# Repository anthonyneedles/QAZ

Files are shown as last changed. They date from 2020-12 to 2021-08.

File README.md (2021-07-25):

# **QAZ**

QAZ 65% Side

## Table of Contents

1. [Boards](#boards)
1. [About This Project](#about-this-project)
    1. [File Structure](#file-structure)
    1. [Dependencies](#dependencies)
1. [Programming](#programming)
1. [Software](#software)
1. [Building](#building)

## **Boards**

### [**QAZ 65%**](docs/guides/QAZ_65.md)

### [**QAZ Media**](docs/guides/QAZ_Media.md)

## **About This Project**

The QAZ project was created as a way for me to learn the USB protocol by writing a bare-metal USB
driver. Since a keyboard is a relatively simple USB device, and I like mechanical keyboards, I
decided that it would be a perfect project. The QAZ project is planned to support various different
keyboard layouts (only 65% and a Media board for now).

This repository holds files for both the software and hardware portions of this project. The
software consists of C++ source and header files, built using Make. Building is only supported
in Debian-based systems. CMSIS is used for some MCU hardware abstraction.

The PCB(s) for the different board versions have their schematic and layouts designed in KiCad,
which are contained in this library and can be manufactured in any generic fabrication house.

There is a maker space at my work that has a laser cutter that can cut acrylic, so decided to try
to keep costs down and make a "sandwich" case, which consists of several stacked layers of acrylic.

### **File Structure**

```
└── QAZ/
    ├── build/
    │   └── CMake build directory
    │
    ├── docs/
    │   │── guides/
    │   │   └── board-specific info, software info, etc.
    │   │
    │   ├── doxygen/
    │   │   └── Doxygen html output
    │   │
    │   └── media/
    │       └── diagrams, pictures, etc.
    │
    ├── hardware/
    │   ├── common/
    │   │   └── hardware utility used by both (e.g. KiCad libraries)
    │   │
    │   └── QAZ_*/
    │       └── PCB/case layer subdirectories for each QAZ configuration
    │
    ├── scripts/
    │   └── useful project scripts (cpplint.py, Doxyfile, etc.)
    │
    ├── src/
    │   └── all source files/module subdirectories, source-level CMakeLists.txt
    │
    └── LICENSE, README, top-level Makefile/CMakeLists.txt
```

The `docs\doxygen` and `build` directories are not tracked, and get made when the project is built.
The files in these directories are removed when the project is cleaned with `make clean`.

## **Programming**

The board programming guide can be found at [`docs/guides/Programming.md`](docs/guides/Programming.md).

## **Software**

The software guide can be found at [`docs/guides/Software.md`](docs/guides/Software.md).

## **Building**

The software building guide can be found at [`docs/guides/Building.md`](docs/guides/Building.md).

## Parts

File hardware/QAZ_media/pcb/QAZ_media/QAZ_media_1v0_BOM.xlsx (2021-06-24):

BOM Index | Part Number | Part Description | QTY | Unit Cost | Extended Cost | Schematic Reference(s) | Product Link
1 | CC0603KRX7R8BB104 | CAP CER 0.1UF 25V X7R 0603 | 4 | $0.10 | $0.40 | C1, C5, C7, C8 | https://www.digikey.com/product-detail/en/yageo/CC0603KRX7R8BB104/311-1341-1-ND/2103125
2 | CC0805KRX5R5BB475 | CAP CER 4.7UF 6.3V X5R 0805 | 1 | $0.17 | $0.17 | C2 | https://www.digikey.com/product-detail/en/yageo/CC0805KRX5R5BB475/311-3422-1-ND/7164443
3 | CL10C160JB8NNNC | CAP CER 16PF 50V C0G/NP0 0603 | 2 | $0.10 | $0.20 | C3, C4 | https://www.digikey.com/product-detail/en/samsung-electro-mechanics/CL10C160JB8NNNC/1276-2204-1-ND/3890290
4 | CL10B105MO8NNWC | CAP CER 1UF 16V X7R 0603 | 2 | $0.10 | $0.20 | C6, C9 | https://www.digikey.com/product-detail/en/samsung-electro-mechanics/CL10B105MO8NNWC/1276-6524-1-ND/5961383
5 | GCM188R72A103KA37D | CAP CER 10000PF 100V X7R 0603 | 2 | $0.10 | $0.20 | C10, C11 | https://www.digikey.com/en/products/detail/murata-electronics/GCM188R72A103KA37D/1641655
6 | USB4085-GF-A | CONN RCPT USB2.0 TYPEC 16POS | 1 | $1.37 | $1.37 | CN1 | https://www.digikey.com/product-detail/en/gct/USB4085-GF-A/2073-USB4085-GF-ACT-ND/9859733
7 | 150060BS75000 | LED BLUE CLEAR 0603 SMD | 1 | $0.16 | $0.16 | D1 | https://www.digikey.com/product-detail/en/w%C3%BCrth-elektronik/150060BS75000/732-4966-1-ND/4489893
8 | 150060VS75000 | LED GREEN CLEAR 0603 SMD | 1 | $0.14 | $0.14 | D2 | https://www.digikey.com/en/products/detail/w%C3%BCrth-elektronik/150060VS75000/4489906
9 | LTST-C190KRKT | LED RED CLEAR CHIP SMD | 1 | $0.24 | $0.24 | D3 | https://www.digikey.com/product-detail/en/lite-on-inc/LTST-C190KRKT/160-1436-1-ND/386816
10 | HLMT-PL00 | LED AMBER CLEAR FLAT T/H AXIAL | 1 | $1.15 | $1.15 | D4 | https://www.digikey.com/en/products/detail/broadcom-limited/HLMT-PL00/637671
11 | S9345-ND | CONN JUMPER SHORTING 1.27MM GOLD | 3 | $0.27 | $0.81 | JP1, JP2, JP3 | https://www.digikey.com/en/products/detail/NPB02SVAN-RC/S9345-ND/2618270
12 | GRPB021VWVN-RC | CONN HEADER VERT 2POS 1.27MM | 3 | $0.25 | $0.75 | JP1, JP2, JP3 | https://www.digikey.com/en/products/detail/GRPB021VWVN-RC/S9014E-02-ND/1786438
13 | ERJ-3EKF2491V | RES SMD 2.49K OHM 1% 1/10W 0603 | 1 | $0.10 | $0.10 | R1 | https://www.digikey.com/en/products/detail/panasonic-electronic-components/ERJ-3EKF2491V/196192
14 | RMCF0603FT10K0 | RES 10K OHM 1% 1/10W 0603 | 12 | $0.10 | $1.20 | R2, R6, R7, R8, R10, R11, R12, R13, R14, R15, R17, R18 | https://www.digikey.com/en/products/detail/yageo/RC0603FR-0710KL/726880
15 | ERJ-3EKF1301V | RES SMD 1.3K OHM 1% 1/10W 0603 | 2 | $0.10 | $0.20 | R3, R4 | https://www.digikey.com/product-detail/en/panasonic-electronic-components/ERJ-3EKF1301V/P1-30KHCT-ND/198082
16 | RC0603FR-071K4L | RES SMD 1.4K OHM 1% 1/10W 0603 | 1 | $0.10 | $0.10 | R5 | https://www.digikey.com/en/products/detail/yageo/RC0603FR-071K4L/726861
17 | RC0603FR-075K1L | RES SMD 5.1K OHM 1% 1/10W 0603 | 2 | $0.10 | $0.20 | R9, R16 | https://www.digikey.com/product-detail/en/yageo/RC0603FR-075K1L/311-5-10KHRCT-ND/730215
18 | RC0603JR-070RL | RES SMD 0 OHM JUMPER 1/10W 0603 | 4 | $0.10 | $0.40 | SB1, SB2, SB3, SB4 | https://www.digikey.com/product-detail/en/yageo/RC0603JR-070RL/311-0.0GRCT-ND/729622
19 | JS102011SCQN | SWITCH SLIDE SPDT 300MA 6V | 1 | $0.73 | $0.73 | SW1 | https://www.digikey.com/en/products/detail/c-k/JS102011SCQN/3753547
20 | NCA2 | KEY STYLE PB, SPST, MOM, BLACK A | 4 | $0.94 | $3.76 | SW2, SW3, SW5, SW6 | https://www.digikey.com/en/products/detail/cit-relay-and-switch/NCA2/12502939
21 | PEC11L-4220F-S0015 | ROTARY ENCODER MECHANICAL 15PPR | 1 | $1.94 | $1.94 | SW4 | https://www.digikey.com/en/products/detail/bourns-inc/PEC11L-4220F-S0015/2440942
22 | OEDNI-75-4-7 | KNOB KNURLED 0.236" METAL | 1 | $7.95 | $7.95 | SW4 | https://www.digikey.com/en/products/detail/kilo-international/OEDNI-75-4-7/5970347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
23 | AP2112K-3.3TRG1 | IC REG LINEAR 3.3V 600MA SOT25 | 1 | $0.49 | $0.49 | U1 | https://www.digikey.com/product-detail/en/diodes-incorporated/AP2112K-3.3TRG1/AP2112K-3.3TRG1DICT-ND/4505257
24 | STM32F042C6T6 | IC MCU 32BIT 32KB FLASH 48LQFP | 1 | $2.94 | $2.94 | U2 | https://www.digikey.com/product-detail/en/stmicroelectronics/STM32F042C6T6/497-14648-ND/4815295
25 | ABM7-8.000MHZ-D2Y-T | CRYSTAL 8.0000MHZ 18PF SMD | 1 | $0.87 | $0.87 | Y1 | https://www.digikey.com/product-detail/en/abracon-llc/ABM7-8.000MHZ-D2Y-T/535-9831-1-ND/2001454
Total |  |  |  |  | $26.67

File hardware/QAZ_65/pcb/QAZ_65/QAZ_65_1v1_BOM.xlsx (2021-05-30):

BOM Index | Part Number | Part Description | QTY | Unit Cost | Extended Cost | Schematic Reference(s) | Product Link
1 | CC0805KRX5R5BB475 | CAP CER 4.7UF 6.3V X5R 0805 | 1 | $0.17 | $0.17 | C1 | https://www.digikey.com/product-detail/en/yageo/CC0805KRX5R5BB475/311-3422-1-ND/7164443
2 | CC0603KRX7R8BB104 | CAP CER 0.1UF 25V X7R 0603 | 7 | $0.10 | $0.70 | C2, C4, C5, C8, C10, C11, C13 | https://www.digikey.com/product-detail/en/yageo/CC0603KRX7R8BB104/311-1341-1-ND/2103125
3 | CL10B105MO8NNWC | CAP CER 1UF 16V X7R 0603 | 4 | $0.10 | $0.40 | C3, C9, C12, C14 | https://www.digikey.com/product-detail/en/samsung-electro-mechanics/CL10B105MO8NNWC/1276-6524-1-ND/5961383
4 | CL10C160JB8NNNC | CAP CER 16PF 50V C0G/NP0 0603 | 2 | $0.10 | $0.20 | C6, C7 | https://www.digikey.com/product-detail/en/samsung-electro-mechanics/CL10C160JB8NNNC/1276-2204-1-ND/3890290
5 | USB4085-GF-A | CONN RCPT USB2.0 TYPEC 16POS | 1 | $1.37 | $1.37 | CN1 | https://www.digikey.com/product-detail/en/gct/USB4085-GF-A/2073-USB4085-GF-ACT-ND/9859733
6 | 150060BS75000 | LED BLUE CLEAR 0603 SMD | 1 | $0.50 | $0.50 | D1 | https://www.digikey.com/product-detail/en/w%C3%BCrth-elektronik/150060BS75000/732-4966-1-ND/4489893
7 | LTST-C191KGKT | LED GREEN CLEAR SMD | 1 | $0.28 | $0.28 | D2 | https://www.digikey.com/product-detail/en/lite-on-inc/LTST-C191KGKT/160-1446-1-ND/386834
8 | LTST-C190KRKT | LED RED CLEAR CHIP SMD | 1 | $0.26 | $0.26 | D3 | https://www.digikey.com/product-detail/en/lite-on-inc/LTST-C190KRKT/160-1436-1-ND/386816
9 | 1N4148FSCT-ND | DIODE SMALL SIGNAL SWITCHING 100V 0.15A 2-PIN DO-35 | 68 | $0.06 | $3.94 | D4, D5, D6, D7, D8, D9, D10, D11, D12, D13, D14, D15, D16, D17, D18, D19, D20, D21, D22, D23, D24, D25, D26, D27, D28, D29, D30, D31, D32, D33, D34, D35, D36, D37, D38, D39, D40, D41, D42, D43, D44, D45, D46, D47, D48, D49, D50, D51, D52, D53, D54, D55, D56, D57, D58, D59, D60, D61, D62, D63, D64, D65, D66, D67, D68, D69, D70, D71 | https://www.digikey.com/products/en?keywords=1N4148FSCT-ND
10 | 19-337C/RSBHGHC-A88/4T | TRI COLOR PCB TOP VIEW SMD LED R | 18 | $0.42 | $7.56 | D72, D73, D74, D75, D76, D77, D78, D79, D80, D81, D82, D83, D84, D85, D86, D87, D88, D89 | https://www.digikey.com/en/products/detail/everlight-electronics-co-ltd/19-337C-RSBHGHC-A88-4T/10059591
11 | S9345-ND | CONN JUMPER SHORTING 1.27MM GOLD | 3 | $0.27 | $0.81 | JP1, JP2, JP3 | https://www.digikey.com/en/products/detail/NPB02SVAN-RC/S9345-ND/2618270
12 | GRPB021VWVN-RC | CONN HEADER VERT 2POS 1.27MM | 3 | $0.25 | $0.75 | JP1, JP2, JP3 | https://www.digikey.com/en/products/detail/GRPB021VWVN-RC/S9014E-02-ND/1786438
13 | RC0603FR-071K69L | RES SMD 1.69K OHM 1% 1/10W 0603 | 1 | $0.10 | $0.10 | R1 | https://www.digikey.com/product-detail/en/yageo/RC0603FR-071K69L/311-1.69KHRCT-ND/729818
14 | RC0603FR-071KL | RES SMD 1K OHM 1% 1/10W 0603 | 5 | $0.10 | $0.50 | R10, R11, R12, R13, R14 | https://www.digikey.com/product-detail/en/yageo/RC0603FR-071KL/311-1.00KHRCT-ND/729790
15 | RC0603FR-0751RL | RES SMD 51 OHM 1% 1/10W 0603 | 6 | $0.10 | $0.60 | R16, R19, R22, R25, R28, R31 | https://www.digikey.com/en/products/detail/yageo/RC0603FR-0751RL/730228
16 | RMCF0603FT20R0 | RES 20 OHM 1% 1/10W 0603 | 12 | $0.10 | $1.20 | R17, R18, R20, R21, R23, R24, R26, R27, R29, R30, R32, R33 | https://www.digikey.com/en/products/detail/stackpole-electronics-inc/RMCF0603FT20R0/1942945
17 | RMCF0603FT10K0 | RES 10K OHM 1% 1/10W 0603 | 4 | $0.10 | $0.40 | R2, R3, R6, R35 | https://www.digikey.com/product-detail/en/stackpole-electronics-inc/RMCF0603FT10K0/RMCF0603FT10K0CT-ND/1943057
18 | RC0603FR-07100KL | RES SMD 100K OHM 1% 1/10W 0603 | 1 | $0.10 | $0.10 | R34 | https://www.digikey.com/en/products/detail/yageo/RC0603FR-07100KL/729836
19 | ERJ-3EKF1301V | RES SMD 1.3K OHM 1% 1/10W 0603 | 2 | $0.10 | $0.20 | R4, R5 | https://www.digikey.com/product-detail/en/panasonic-electronic-components/ERJ-3EKF1301V/P1-30KHCT-ND/198082
20 | RC0603FR-072KL | RES SMD 2K OHM 1% 1/10W 0603 | 2 | $0.10 | $0.20 | R7, R8 | https://www.digikey.com/en/products/detail/yageo/RC0603FR-072KL/727009
21 | RC0603FR-075K1L | RES SMD 5.1K OHM 1% 1/10W 0603 | 2 | $0.10 | $0.20 | R9, R15 | https://www.digikey.com/product-detail/en/yageo/RC0603FR-075K1L/311-5-10KHRCT-ND/730215
22 | RC0603JR-070RL | RES SMD 0 OHM JUMPER 1/10W 0603 | 21 | $0.10 | $2.10 | SB1, SB2, SB3, SB4, SB5, SB6, SB7, SB8, SB9, SB10, SB11, SB12, SB13, SB14, SB15, SB16, SB17, SB18, SB19, SB20, SB21 | https://www.digikey.com/product-detail/en/yageo/RC0603JR-070RL/311-0.0GRCT-ND/729622
23 | JS102011SCQN | SWITCH SLIDE SPDT 300MA 6V | 1 | $0.73 | $0.73 | SW1 | https://www.digikey.com/en/products/detail/c-k/JS102011SCQN/3753547
24 | - | CHERRY MX SWITCH, CLEAR, PCB MOUNT | 68 |  |  | SW2, SW3, SW4, SW5, SW6, SW7, SW8, SW9, SW10, SW11, SW12, SW13, SW14, SW15, SW16, SW17, SW18, SW19, SW20, SW21, SW22, SW23, SW24, SW25, SW26, SW27, SW28, SW29, SW30, SW31, SW32, SW33, SW34, SW35, SW36, SW37, SW38, SW39, SW40, SW41, SW42, SW43, SW44, SW45, SW46, SW47, SW48, SW49, SW50, SW51, SW52, SW53, SW54, SW55, SW56, SW57, SW58, SW59, SW60, SW61, SW62, SW63, SW64, SW65, SW66, SW67, SW68, SW69
25 | AP2112K-3.3TRG1 | IC REG LINEAR 3.3V 600MA SOT25 | 1 | $0.49 | $0.49 | U1 | https://www.digikey.com/product-detail/en/diodes-incorporated/AP2112K-3.3TRG1/AP2112K-3.3TRG1DICT-ND/4505257
26 | STM32F042C6T6 | IC MCU 32BIT 32KB FLASH 48LQFP | 1 | $2.94 | $2.94 | U2 | https://www.digikey.com/product-detail/en/stmicroelectronics/STM32F042C6T6/497-14648-ND/4815295
27 | IS31FL3746A-QFLS4-TR | IC LED DRIVER LIN DIM | 1 | $2.11 | $2.11 | U3 | https://www.digikey.com/en/products/detail/lumissil-microsystems/IS31FL3746A-QFLS4-TR/9759708
28 | ABM7-8.000MHZ-D2Y-T | CRYSTAL 8.0000MHZ 18PF SMD | 1 | $1.00 | $1.00 | Y1 | https://www.digikey.com/product-detail/en/abracon-llc/ABM7-8.000MHZ-D2Y-T/535-9831-1-ND/2001454
Total |  |  |  |  | $29.81

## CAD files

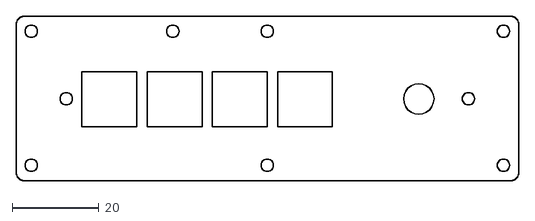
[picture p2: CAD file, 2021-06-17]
hardware/QAZ_media/layers/plate_layer_v1.dxf
115.7 x 37.9

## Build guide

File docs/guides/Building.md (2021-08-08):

# **QAZ Building**

## **Table of Contents**

1. [Dependencies](#dependencies)
1. [Make](#make)
1. [CMake](#cmake)
1. [Output](#output)

## **Dependencies**

Required APT packages for building:
- gcc-arm-none-eabi
- build-essential
- cmake (>= 3.16.3)

Required APT packages for utility targets and debugging:
- gdb-multiarch
- openocd
- stlink-tools
- doxygen
- graphviz
- python

Additionally, KiCad is used for PCB design.

## **Make**

QAZ uses `make` for top-level project building. This [Makefile](../../Makefile) handles all
building commands. These are the available commands:

- `QAZ` - Build complete software target

- `all` - Build software target, doxygen, and lint

- `docs` - Use Doxygen to create project documentation (with Graphviz graphs)

- `clean` - Removes all built files

- `lint` - Run cpplint.py on `src/`

- `flash` - Flash binary at 0x08000000, `make QAZ` if no binary

- `help` - Display the above

There are several variables that the user can set in a "user config"
Makefile. This file is *not* tracked by Git, so that local changes to it don't
need to be stashed/removed when committing. There exists a template of this
file [UserConfig.mk.template](../../UserConfig.mk.template) that the user
would ideally copy to `UserConfig.mk`, and make any desired changes.

These are the variables set in the user config:

- `BUILD_TYPE` - Debug or Release (i.e. debug print statements/asserts or not)

- `BOARD` - Which board to build for (dictates BSP)

A dummy marker file `.rebuild-marker` is used to ensure that whenever the top level
[Makefile](../../Makefile) is changed the system ALWAYS rebuilds. This ensures that partial
builds don't occur when changing the above variables.

## **CMake**

When building the output project, `cmake` will be invoked to generate the source-level
[Makefile](../../Makefile) in the `build/` directory, which will then be used to compile and
link the output executable.

The top-level [CMakeLists.txt](../../CMakeLists.txt) expects three variables: `TARGET`,
`CMAKE_BUILD_TYPE`, and `BSP`, which is nominally passed in by the top-level
[Makefile](../../Makefile) from the `TARGET`, `BUILD_TYPE`, and `BOARD` variables (respectively).
This file also defines our compilers/linkers, as well as all of the flags we pass to them. `src/`
is added as a subdirectory.

The source-level [CMakeLists](../../src/CMakeLists.txt) expects the same variables as above. This
file defines all C++, C, and Assembly files (paths relative to `src/`), as well as include
directories.

## **Output**

After building, output targets can be found in `build/src`. The default output target is `QAZ.elf`.
This is copied and converted to `QAZ.bin`. To help tracking .elf/.bin files, both are then copied
and renamed to: `${BOARD}_${BUILD_TYPE}_${GIT_STATE}_${GIT_HASH}.*` (`GIT_STATE` is either
`CLEAN` or `DIRTY`).

The .elf output can be used to program the given board by following the
[QAZ Programming guide](Programming.md).

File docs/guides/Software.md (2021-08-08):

# **QAZ Software**

## **Table of Contents**

1. [Clocks](#clocks)
1. [Time Slice Loop](#time-slice-loop)
1. [USB](#usb)
1. [Keyboard](#keyboard)
1. [Persistent Data](#persistent-data)

## **Clocks**

The STM32F042C6 has a default HS clock of 8MHz, and a HSI48 48MHz clock, which is specifically for
the USB peripheral. This clock has a terrible accuracy of +/-3% at room temperature, which is out
of spec of USB 2.0 tolerance. However, the USB peripheral has a special Clock Recovery System (CRS)
which dynamically adjusts the oscillator an adequate amount.

In the initial steps of this design, this HSI48 was used, but as of QAZ board v0.1 an external 8MHz
crystal supplies the HSE oscillator, which gets multiplied to 48MHz from the PLL, then finally
feeds the system core and USB peripheral.

## **Time Slice Loop**

The QAZ firmware does not operate on an RTOS, because it doesn't require stringent timing, but
rather a time slice superloop. The configuration of this is defined in
[core/time_slice.hpp](../../src/core/time_slice.hpp).

Tasks must be registered to the timeslice scheduler by calling `timeslice::register_task()`, with
the task period and function as parameters. Registered tasks are entered in a statically defined
task registry, so the maximum number of tasks is defined by `MAX_NUM_TASKS`.

While the timeslice loop is running, the internal 'time slice manager task' will make sure that
each task gets a chance to run every loop period. Specific task periods are created by only
calling the task function every N time slices (where N = Task Period / Loop Period).

**Task periods must be multiples of of the timeslice period. For a given set of task periods,
the timeslice period should be as large as possible.**

Currently, the time slice loop (`LOOP_PERIOD_MS`) is 5ms.

Task periods:
- **LED Heartbeat Task** - 500ms
- **Key Matrix Scan Task** - 20ms
- **Lighting Task** - 5ms
- **USB HID KB Task** - 20ms
- **USB HID Consumer Task** - 10ms

## **USB**

The QAZ project uses an entirely self-written USB low-level driver, which interacts directly with
the STM32 USB hardware peripheral. Additionally, there are Keyboard device and Consumer device USB
HID drivers, which utilizes the low-level driver to perform the required HID initialization and
reporting.

In the device descriptor the following fields are set for each board:
- idVendor = `0xC01D`
- idProduct = `0xAA22`
- bcdDevice = Version of board (e.g. `1.10`)
- iManufacturer = String descriptor 1 ("`anthonyneedles`")
- iProduct =  String descriptor 2 (e.g. "`qaz media`")

## **Keyboard**

The keyboard layout for a QAZ configuration is defined in the BSP file for the board. `COLS` and
`ROWS` define the physical pins of the key matrix. The `BASE_TABLE` and `FN_TABLE` defines the
keyboard layout for a given row and column pin, with column0/row0 being the "top left" of the
keyboard.

The entries in the key layout table correspond to a given entry in the USB HID usages table, as
well as "extra" codes added that correspond not to actual codes, but actions to perform. For
instance, changing the keyboard RGB LED brightness and color. `NONE` is used when no keycode or
action corresponds to with the key on the layer.

There is a special key called `FN`, which when pressed switches the key layout layer from Base to
Fn. This means the any other key also pressed with the `FN` key will result in the `FN_TABLE`
being used to translate key presses into key codes/actions rather than `BASE_TABLE`. This allows
almost double the amount of "keys" on the keyboard.

For example, in the QAZ 65%, pressing just the "1/!" physical key results in the Base keycode
(0x1E) for that key being sent to the host. If instead the "1/!" physical key AND the "FN"
physical key were pressed, then the Fn keycode (0x3A, the F1 keycode) for that given key is
sent instead.

It important to keep in mind, that since keyboard layouts are not exact grids, not every column/row
pin corresponds to a physical pin, but must be defined in each table grid (and given a `NONE` value).

Additionally, any of the keys can also be defined in `CALLBACK_KEY_TABLE`, which (when a key with
that code is pressed) results in the key NOT being placed in the output key buffer (used by the USB
KB HID task to send keycodes to the host), but having a callback (initially defined as `weak`)
called. This allows other modules defining the callback and implementing a hook to execute when the
given key is pressed (seen in RGB LED module).

## **Persistent Data**

There are several data words that are saved in the internal flash, as it is desired that they
persist between PORs (for instance, the lighting settings). This is achieved by emulating the
flash as EEPROM.

This emulation requires two full flash pages be used. In order to maximize the available flash for
the program, the last two pages are used. Since each page is 1kB, this means that the available
flash in the STM32F042C6 for the program is 30kB, with the last 2kB being reserved.

New data words can be added by adding entries to the `PERSIST_DATA_TABLE` in
[src/qaz/persist.hpp](../../src/flash/persist.hpp), and increasing `NB_OF_VAR` in
[src/flash/eeprom.h](../../src/flash/eeprom.h).

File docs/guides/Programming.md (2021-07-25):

# **QAZ Programming**

## **Table of Contents**

1. [Required Software](#required-software)
1. [Programming](#programming)

## **Required Software**

[STM32CubeProgrammer](https://www.st.com/en/development-tools/stm32cubeprog.html) is used to
connect to the STM32 bootloader, to program a board via USB DFU (nominally) or SWD (JTAG).

## **Programming**

The following steps should be followed to program a given QAZ board.

1. Unplug the board and flip the boot switch, accessible on the back of the board, to the "PG" 
side.
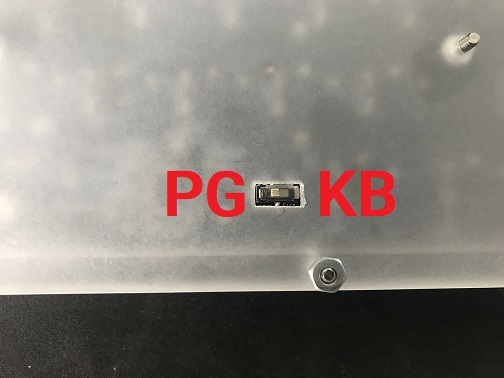
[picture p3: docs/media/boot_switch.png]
QAZ Boot Switch

1. Plug the board back in, and open STM32CubeProgrammer.
1. Select "USB" as method of programming. "Port" should be "USB1", as the bootloader device should
be automatically detected. If not, hit the refresh button to the right. When the PID/VID are
filled, hit the "Connect" button, which should result in "Data read successfully" in the log. Open
the "Erasing & Programming" window by clicking on the second icon on the left. Open "Browse", and
select the desired .elf program file. Finally, click "Start Programming". 
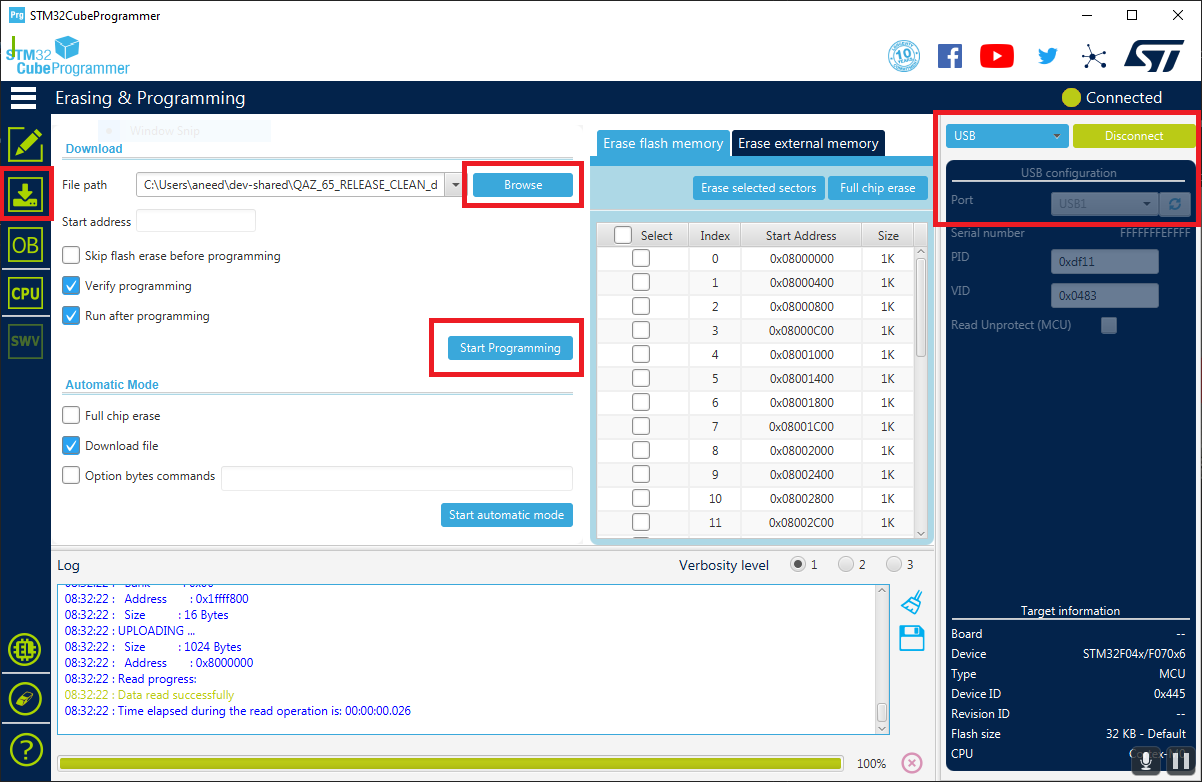
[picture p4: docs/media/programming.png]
STM32 Bootloader

1. Unplug the board, flip the boot switch to the "KB" side, and plug the board back in. The board
should now be programmed.

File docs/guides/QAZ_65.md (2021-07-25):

# **QAZ 65% Keyboard**

QAZ 65% Side

## **Table of Contents**

1. [About This Board](#about-this-board)
1. [Software](#software)
1. [Hardware](#hardware)
    1. [PCB](#pcb)
    1. [Case](#case)
1. [Previous Versions](#previous-versions)
    1. [v1.0](#v1.0)

## **About This Board**

The QAZ 65% is a 68-key keyboard in a non-standard configuration. It features RGB back lighting,
with configurable lighting.

QAZ 65% Top

### **KLE Layout**

```
["Esc","!\n1","@\n2","#\n3","$\n4","%\n5","^\n6","&\n7","*\n8","(\n9",")\n0","_\n-","+\n=",{w:2},"Backspace","~\n`"],
[{w:1.5},"Tab","Q","W","E","R","T","Y","U","I","O","P","{\n[","}\n]",{w:1.5},"|\n\\","Del"],
[{w:1.75},"Caps Lock","A","S","D","F","G","H","J","K","L",":\n;","\"\n'",{w:2.25},"Enter","PgUp"],
[{w:2.25},"Shift","Z","X","C","V","B","N","M","<\n,",">\n.","?\n/",{w:1.75},"Shift","↑","PgDn"],
[{w:1.25},"Ctrl",{w:1.25},"Opt",{w:1.25},"Alt",{a:7,w:6.25},"",{a:4},"Alt","Ctrl","Fn","←","↓","→"]
```

## **Software**

The software target for this board can be selected by setting `BOARD` to `QAZ_65`.

This will switch in software modules specific to the QAZ 65% board, such as the keyboard matrix,
RGB LED lighting, USB Keyboard HID driver, etc.

## **Hardware**

The QAZ 65% keyboard hardware is comprised of a 2-layer PCB inside of an acrylic layer "sandwich"
case.

The latest version of the QAZ 65% hardware is tagged as
[`hw/qaz_65_v1.1`](https://github.com/anthonyneedles/QAZ/releases/tag/hw%2Fqaz_65_v1.1).

### **PCB**

QAZ 65% PCB

The KiCad project for the board PCB is located in
[`hardware/QAZ_65/pcb/QAZ_65/`](../../hardware/QAZ_65/pcb/QAZ_65/).

The Bill of Materials for the electronic components can be found at
[`hardware/QAZ_65/pcb/QAZ_65/QAZ_65_1v1_BOM.xlsx`](../../hardware/QAZ_65/pcb/QAZ_65/QAZ_65_1v1_BOM.xlsx).

### **Case**

The vector files for the case layers are located in
[`hardware/QAZ_65/layers/`](../../hardware/QAZ_65/pcb/QAZ_65/).

There are four layers (from bottom to top):

- **Bottom Layer** - Mostly solid bottom layer, with only drill holes for mounting screws and the
boot switch. 5mm acrylic, frosted clear.
- **Closed Layer** - Board outline (middle) layer, with outside drill holes. 5mm acrylic, frosted
clear.
- **Open Layer** - Board outline (middle) layer, with outside drill holes and opening for USB-C
port. 3mm acrylic, frosted clear.
- **Plate Layer** - Top layer with cutouts for all of the key switches, stabilizers, and drill
holes. 1.6mm PCB, matte black.

The mounting screws/nuts used are of size #4-40.

Rubber feet are added to the bottom of the board to prevent mounting screws from scratching the
surface below.

### **Side Cut Diagram**

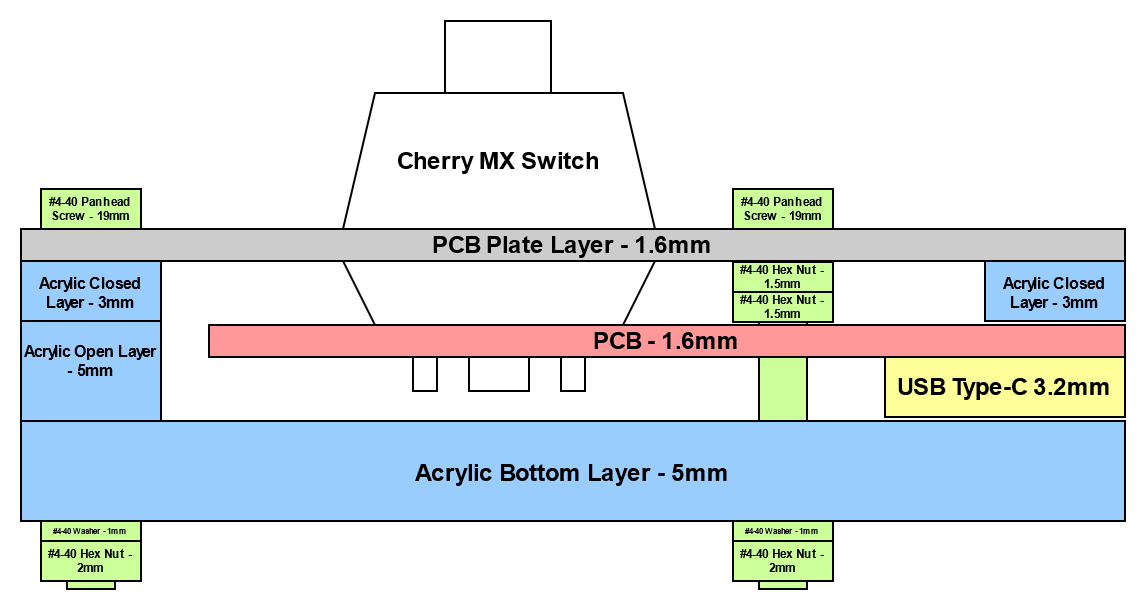
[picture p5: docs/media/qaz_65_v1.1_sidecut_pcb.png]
QAZ 65% Case Side-cut


## **Previous Versions**

### **v1.0**

The v1.0 version of the QAZ 65% hardware is tagged as
[`hw/qaz_65_v1.0`](https://github.com/anthonyneedles/QAZ/releases/tag/hw%2Fqaz_65_v1.0).

This release was proceeded by v1.1, which changed the LED driver, to allow for the driving of many
more RGB LEDs, to "spread" out the backlight. Also, the SWD port was removed, but the signals to
the MCU can still be accessed by several test points located on the board.

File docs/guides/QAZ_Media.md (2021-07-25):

# **QAZ Media**

QAZ Media Side

## **Table of Contents**

1. [About This Board](#about-this-board)
1. [Software](#software)
1. [Hardware](#hardware)
    1. [PCB](#pcb)
    1. [Case](#case)

## **About This Board**

The QAZ Media board is an ancillary device for controlling media. It features buttons for
pausing/skipping/etc., as well as a volume knob.

QAZ Media Top

## **Software**

The software target for this board can be selected by setting `BOARD` to `QAZ_MEDIA`.

This will switch in software modules specific to the QAZ Media board, such rotary encoding, USB
Consumer HID driver, etc.

## **Hardware**

The QAZ Media keyboard hardware is comprised of a 2-layer PCB inside of an acrylic layer "sandwich"
case.

The latest version of the QAZ Media hardware is tagged as
[`hw/qaz_media_v1.0`](https://github.com/anthonyneedles/QAZ/releases/tag/hw%2Fqaz_media_v1.0).

### **PCB**

QAZ Media PCB

The KiCad project for the board PCB is located in
[`hardware/QAZ_media/pcb/QAZ_media/`](../../hardware/QAZ_media/pcb/QAZ_media/).

The Bill of Materials for the electronic components can be found at
[`hardware/QAZ_media/pcb/QAZ_media/QAZ_media_1v0_BOM.xlsx`](../../hardware/QAZ_media/pcb/QAZ_media/QAZ_media_1v0_BOM.xlsx).

### **Case**

The vector files for the case layers are located in
[`hardware/QAZ_media/layers/`](../../hardware/QAZ_media/pcb/QAZ_media/).

There are four layers (from bottom to top):

- **Bottom Layer** - Mostly solid bottom layer, with only drill holes for mounting screws and the
boot switch. 5mm acrylic, frosted clear.
- **Closed Layer** - Board outline (middle) layer, with outside drill holes. 5mm acrylic, frosted
clear.
- **Open Layer** - Board outline (middle) layer, with outside drill holes and opening for USB-C
port. 3mm acrylic, frosted clear.
- **Plate Layer** - Top layer with cutouts for all of the key switches, stabilizers, and drill
holes. 1.6mm PCB, matte black.

The mounting screws/nuts used are of size #4-40.

Rubber feet are added to the bottom of the board to prevent mounting screws from scratching the
surface below.

### **Side Cut Diagram**

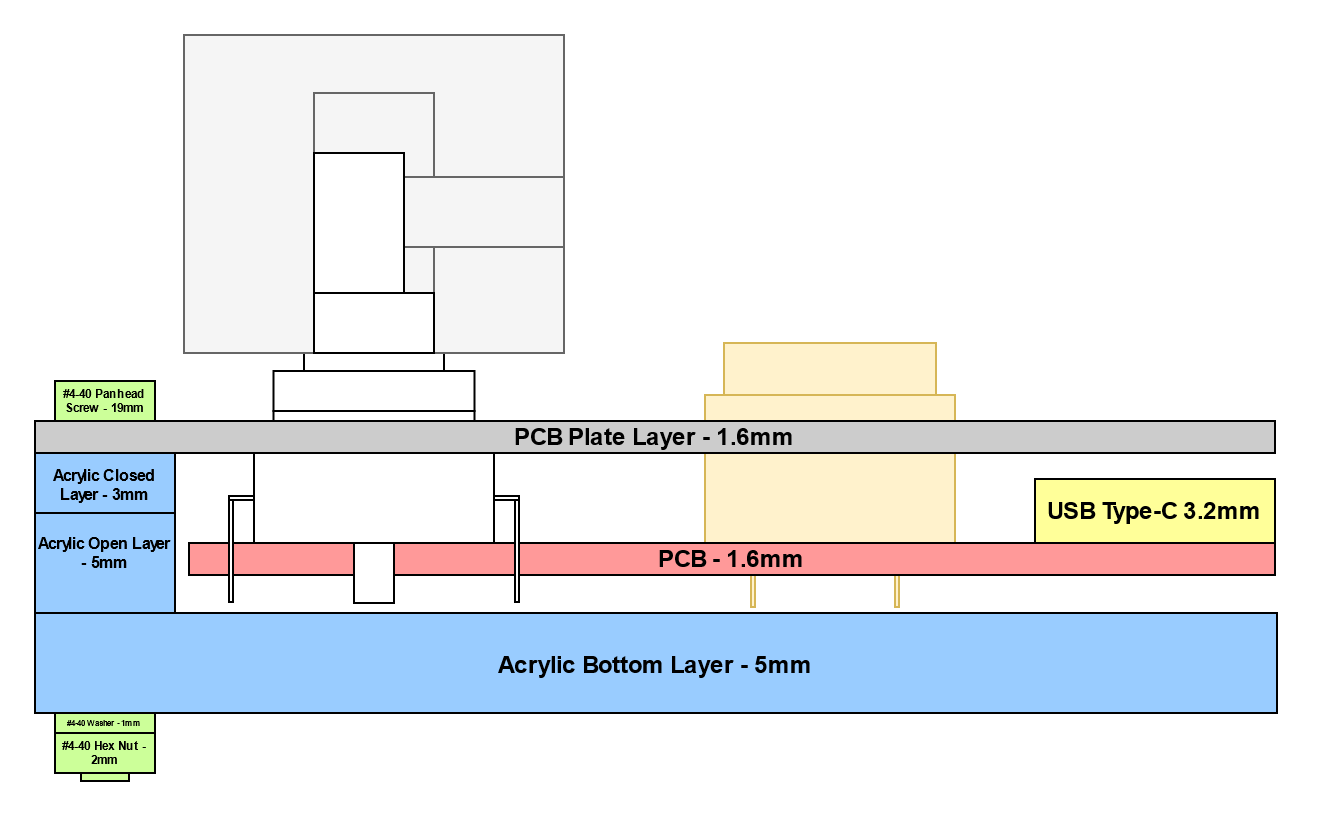
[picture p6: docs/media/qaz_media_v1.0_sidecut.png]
QAZ Media Case Side-cut


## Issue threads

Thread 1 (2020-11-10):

Low-profile RESET button

anthonyneedles, 2020-11-10:
Change out the switch to a lower profile one so that it does not impede space.

anthonyneedles, 2020-12-07:
this is implemented in the QAZ 65% v1.0

Closed 2020-12-07.

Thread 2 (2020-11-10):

Fix QAZ Testboard

anthonyneedles, 2020-11-10:
For resolution, fix the QAZ Testboard. This includes:

- Flipping the USB connector

- Swap I2C SCL/SDA lines

anthonyneedles, 2021-06-29:
Testboard now deprecated

Closed 2021-06-29.

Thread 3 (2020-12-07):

Add switch to BOOT0 pin

anthonyneedles, 2020-12-07:
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

BOOT0 determines where the MCU boots. The USB DFU bootloader is located in the system memory, which means we need to be able to pull this pin high (currently pulled low).

On the QAZ 65% v1.0, there are pads for pullup (R1) and pulldown (R2, DNP) resistor, but that isn't very useful for a user. So a switch should be used to allow easily going between normal and USB DFU mode.

anthonyneedles, 2021-05-30:
this is in QAZ 65% v1.1

Closed 2021-05-30.

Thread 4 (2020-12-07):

Add bottom layer holes for reset button and BOOT0 switch

anthonyneedles, 2020-12-07:
Adding little cutout holes allows access for the user to the reset button and BOOT0 pin.

anthonyneedles, 2021-05-30:
this is in QAZ 65% bottom layer v2 (no reset button hole, no reset button)

Closed 2021-05-30.

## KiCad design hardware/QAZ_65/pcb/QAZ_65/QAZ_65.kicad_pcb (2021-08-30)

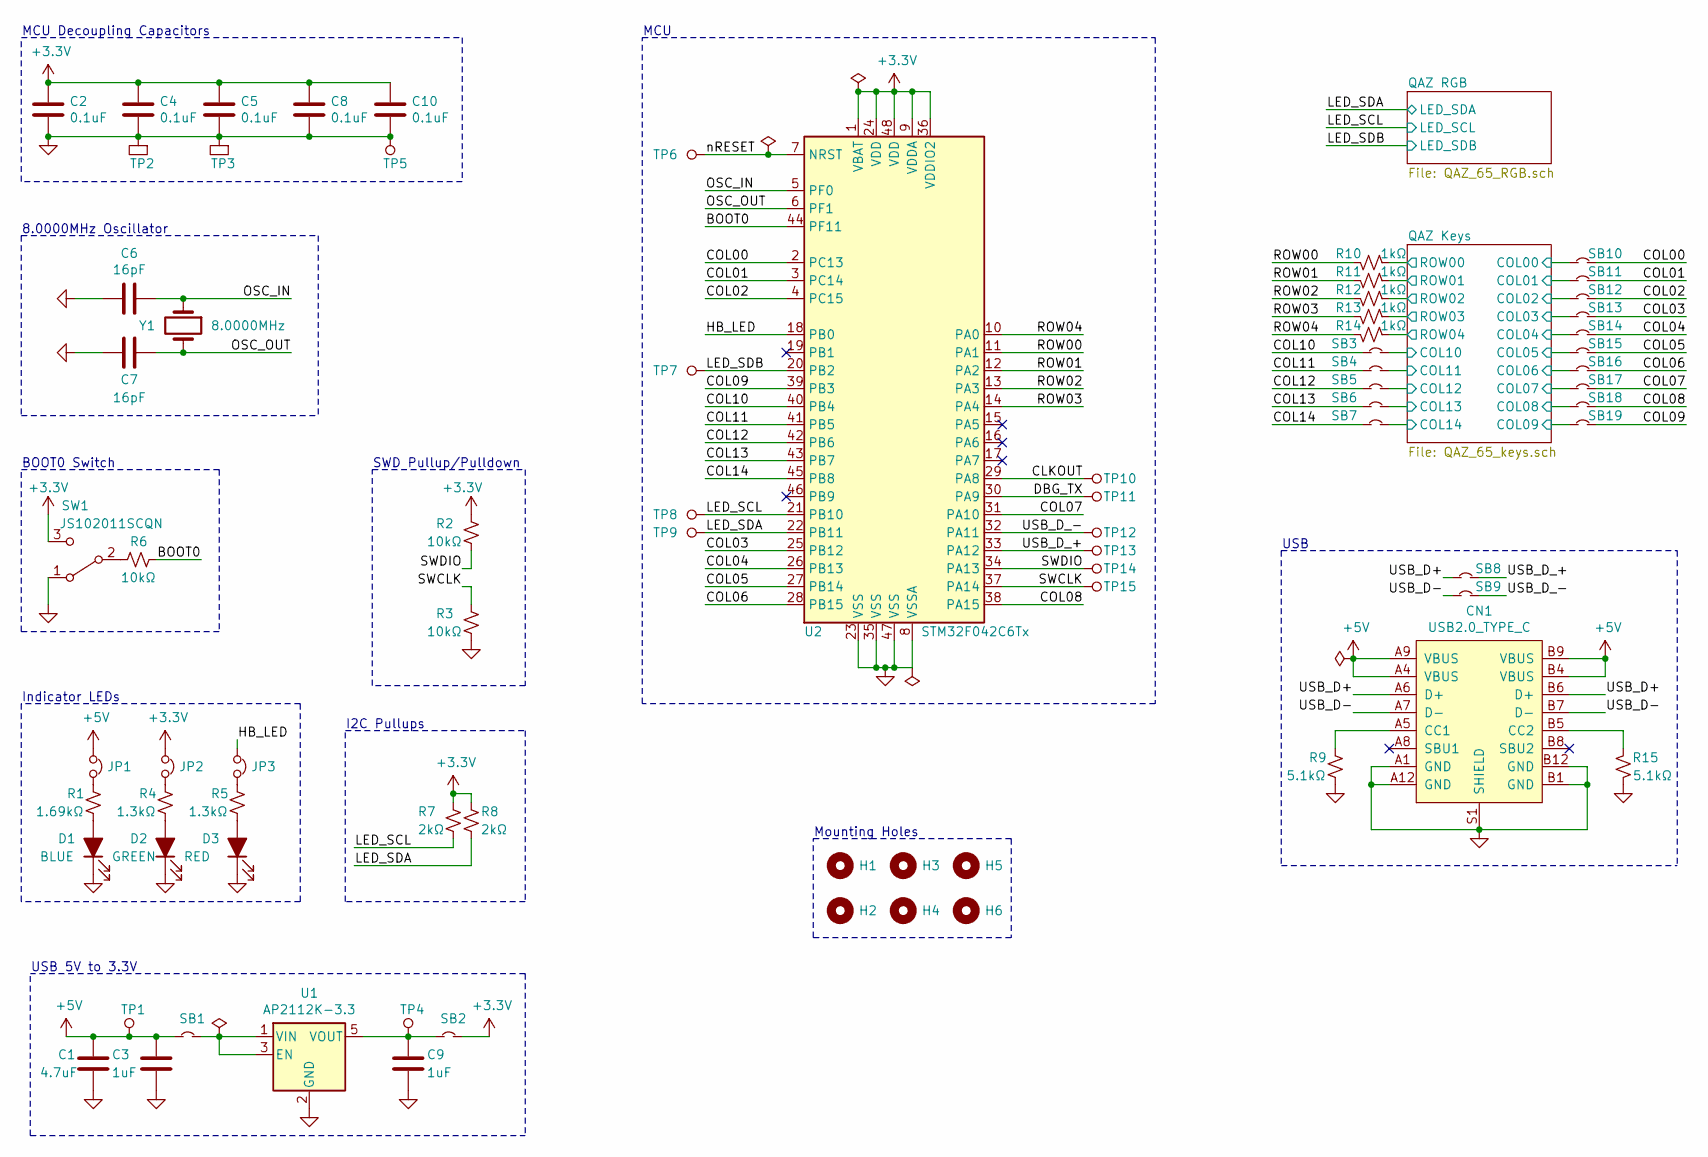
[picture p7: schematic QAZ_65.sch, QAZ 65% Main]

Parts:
C1: 4.7uF; C_0805_2012Metric_Pad1.15x1.40mm_HandSolder
C2, C4, C5, C8, C10: 0.1uF; C_0603_1608Metric_Pad1.05x0.95mm_HandSolder
C3, C9: 1uF; C_0603_1608Metric_Pad1.05x0.95mm_HandSolder
C6, C7: 16pF; C_0603_1608Metric_Pad1.05x0.95mm_HandSolder
CN1: USB2.0_TYPE_C; USB_C_GCT_USB4085
D1: BLUE; R_0603_1608Metric_Pad1.05x0.95mm_HandSolder
D2: GREEN; R_0603_1608Metric_Pad1.05x0.95mm_HandSolder
D3: RED; R_0603_1608Metric_Pad1.05x0.95mm_HandSolder
H1, H2, H3, H4, H5, H6: MountingHole; 4-40_NPTH
JP1, JP2, JP3: Jumper_NC_Small; PinHeader_1x02_P1.27mm_Vertical
R1: 1.69kΩ; R_0603_1608Metric_Pad1.05x0.95mm_HandSolder
R2, R3, R6: 10kΩ; R_0603_1608Metric_Pad1.05x0.95mm_HandSolder
R4, R5: 1.3kΩ; R_0603_1608Metric_Pad1.05x0.95mm_HandSolder
R7, R8: 2kΩ; R_0603_1608Metric_Pad1.05x0.95mm_HandSolder
R9, R15: 5.1kΩ; R_0603_1608Metric_Pad1.05x0.95mm_HandSolder
R10, R11, R12, R13, R14: 1kΩ; R_0603_1608Metric_Pad1.05x0.95mm_HandSolder
SB1, SB2, SB3, SB4, SB5, SB6, SB7, SB8, SB9, SB10, SB11, SB12, SB13, SB14, SB15, SB16, SB17, SB18, SB19: SolderBridge; R_0603_1608Metric_Pad1.05x0.95mm_HandSolder
SW1: JS102011SCQN; JS102011SCQN_SPDT
TP1, TP4, TP5, TP6, TP7, TP8, TP9, TP10, TP11, TP12, TP13, TP14, TP15: TestPoint; TestPoint_Thruhole_1.0mm
TP2, TP3: TestPoint_SMD_1812; TestPoint_SMD_1812_HS
U1: AP2112K-3.3; SOT-23-5
U2: STM32F042C6Tx; LQFP-48_7x7mm_P0.5mm
Y1: 8.0000MHz; Crystal_SMD_Abracon_ABM7-2Pin_6.0x3.5mm_HS

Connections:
+3V3: C2.2, C4.2, C5.2, C8.2, C10.2, JP2.1, R2.2, R7.2, R8.2, SB2.2, SW1.3 (C), U2.1 (VBAT), U2.9 (VDDA), U2.24 (VDD), U2.36 (VDDIO2), U2.48 (VDD); also elsewhere on the board
+5V: C1.2, C3.2, CN1.A4 (VBUS), CN1.A9 (VBUS), CN1.B4 (VBUS), CN1.B9 (VBUS), JP1.1, SB1.1, TP1.1; also elsewhere on the board
/BOOT0: R6.2, U2.44 (PF11)
/CLKOUT: TP10.1, U2.29 (PA8)
/COL00: SB10.2, U2.2 (PC13)
/COL01: SB11.2, U2.3 (PC14)
/COL02: SB12.2, U2.4 (PC15)
/COL03: SB13.2, U2.25 (PB12)
/COL04: SB14.2, U2.26 (PB13)
/COL05: SB15.2, U2.27 (PB14)
/COL06: SB16.2, U2.28 (PB15)
/COL07: SB17.2, U2.31 (PA10)
/COL08: SB18.2, U2.38 (PA15)
/COL09: SB19.2, U2.39 (PB3)
/COL10: SB3.1, U2.40 (PB4)
/COL11: SB4.1, U2.41 (PB5)
/COL12: SB5.1, U2.42 (PB6)
/COL13: SB6.1, U2.43 (PB7)
/COL14: SB7.1, U2.45 (PB8)
/DBG_TX: TP11.1, U2.30 (PA9)
/HB_LED: JP3.1, U2.18 (PB0)
/LED_SCL: R7.1, TP8.1, U2.21 (PB10); also elsewhere on the board
/LED_SDA: R8.1, TP9.1, U2.22 (PB11); also elsewhere on the board
/LED_SDB: TP7.1, U2.20 (PB2); also elsewhere on the board
/OSC_IN: C6.1, U2.5 (PF0), Y1.1
/OSC_OUT: C7.1, U2.6 (PF1), Y1.2
/QAZ Keys/COL00: SB10.1; also elsewhere on the board
/QAZ Keys/COL01: SB11.1; also elsewhere on the board
/QAZ Keys/COL02: SB12.1; also elsewhere on the board
/QAZ Keys/COL03: SB13.1; also elsewhere on the board
/QAZ Keys/COL04: SB14.1; also elsewhere on the board
/QAZ Keys/COL05: SB15.1; also elsewhere on the board
/QAZ Keys/COL06: SB16.1; also elsewhere on the board
/QAZ Keys/COL07: SB17.1; also elsewhere on the board
/QAZ Keys/COL08: SB18.1; also elsewhere on the board
/QAZ Keys/COL09: SB19.1; also elsewhere on the board
/QAZ Keys/COL10: SB3.2; also elsewhere on the board
/QAZ Keys/COL11: SB4.2; also elsewhere on the board
/QAZ Keys/COL12: SB5.2; also elsewhere on the board
/QAZ Keys/COL13: SB6.2; also elsewhere on the board
/QAZ Keys/COL14: SB7.2; also elsewhere on the board
/QAZ Keys/ROW00: R10.1; also elsewhere on the board
/QAZ Keys/ROW01: R11.1; also elsewhere on the board
/QAZ Keys/ROW02: R12.1; also elsewhere on the board
/QAZ Keys/ROW03: R13.1; also elsewhere on the board
/QAZ Keys/ROW04: R14.1; also elsewhere on the board
/ROW00: R10.2, U2.11 (PA1)
/ROW01: R11.2, U2.12 (PA2)
/ROW02: R12.2, U2.13 (PA3)
/ROW03: R13.2, U2.14 (PA4)
/ROW04: R14.2, U2.10 (PA0)
/SWCLK: R3.2, TP15.1, U2.37 (PA14)
/SWDIO: R2.1, TP14.1, U2.34 (PA13)
/USB_D+: CN1.A6 (D+), CN1.B6 (D+), SB8.1
/USB_D-: CN1.A7 (D-), CN1.B7 (D-), SB9.1
/USB_D_+: SB8.2, TP13.1, U2.33 (PA12)
/USB_D_-: SB9.2, TP12.1, U2.32 (PA11)
/nRESET: TP6.1, U2.7 (NRST)
GND: C1.1, C2.1, C3.1, C4.1, C5.1, C6.2, C7.2, C8.1, C9.1, C10.1, CN1.A1 (GND), CN1.A12 (GND), CN1.B1 (GND), CN1.B12 (GND), CN1.S1 (SHIELD), D1.1 (K), D2.1 (K), D3.1 (K), R3.1, R9.1, R15.1, SW1.1 (A), TP2.1, TP3.1, TP5.1, U1.2 (GND), U2.8 (VSSA), U2.23 (VSS), U2.35 (VSS), U2.47 (VSS); also elsewhere on the board
unnamed: C9.2, SB2.1, TP4.1, U1.5 (VOUT)
unnamed: CN1.A5 (CC1), R9.2
unnamed: CN1.B5 (CC2), R15.2
unnamed: D1.2 (A), R1.1
unnamed: D2.2 (A), R4.1
unnamed: D3.2 (A), R5.1
unnamed: JP1.2, R1.2
unnamed: JP2.2, R4.2
unnamed: JP3.2, R5.2
unnamed: R6.1, SW1.2 (B)
unnamed: SB1.2, U1.1 (VIN), U1.3 (EN)

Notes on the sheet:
USB 5V to 3.3V
MCU Decoupling Capacitors
8.0000MHz Oscillator
BOOT0 Switch
Indicator LEDs
I2C Pullups
MCU
SWD Pullup/Pulldown
USB
Mounting Holes

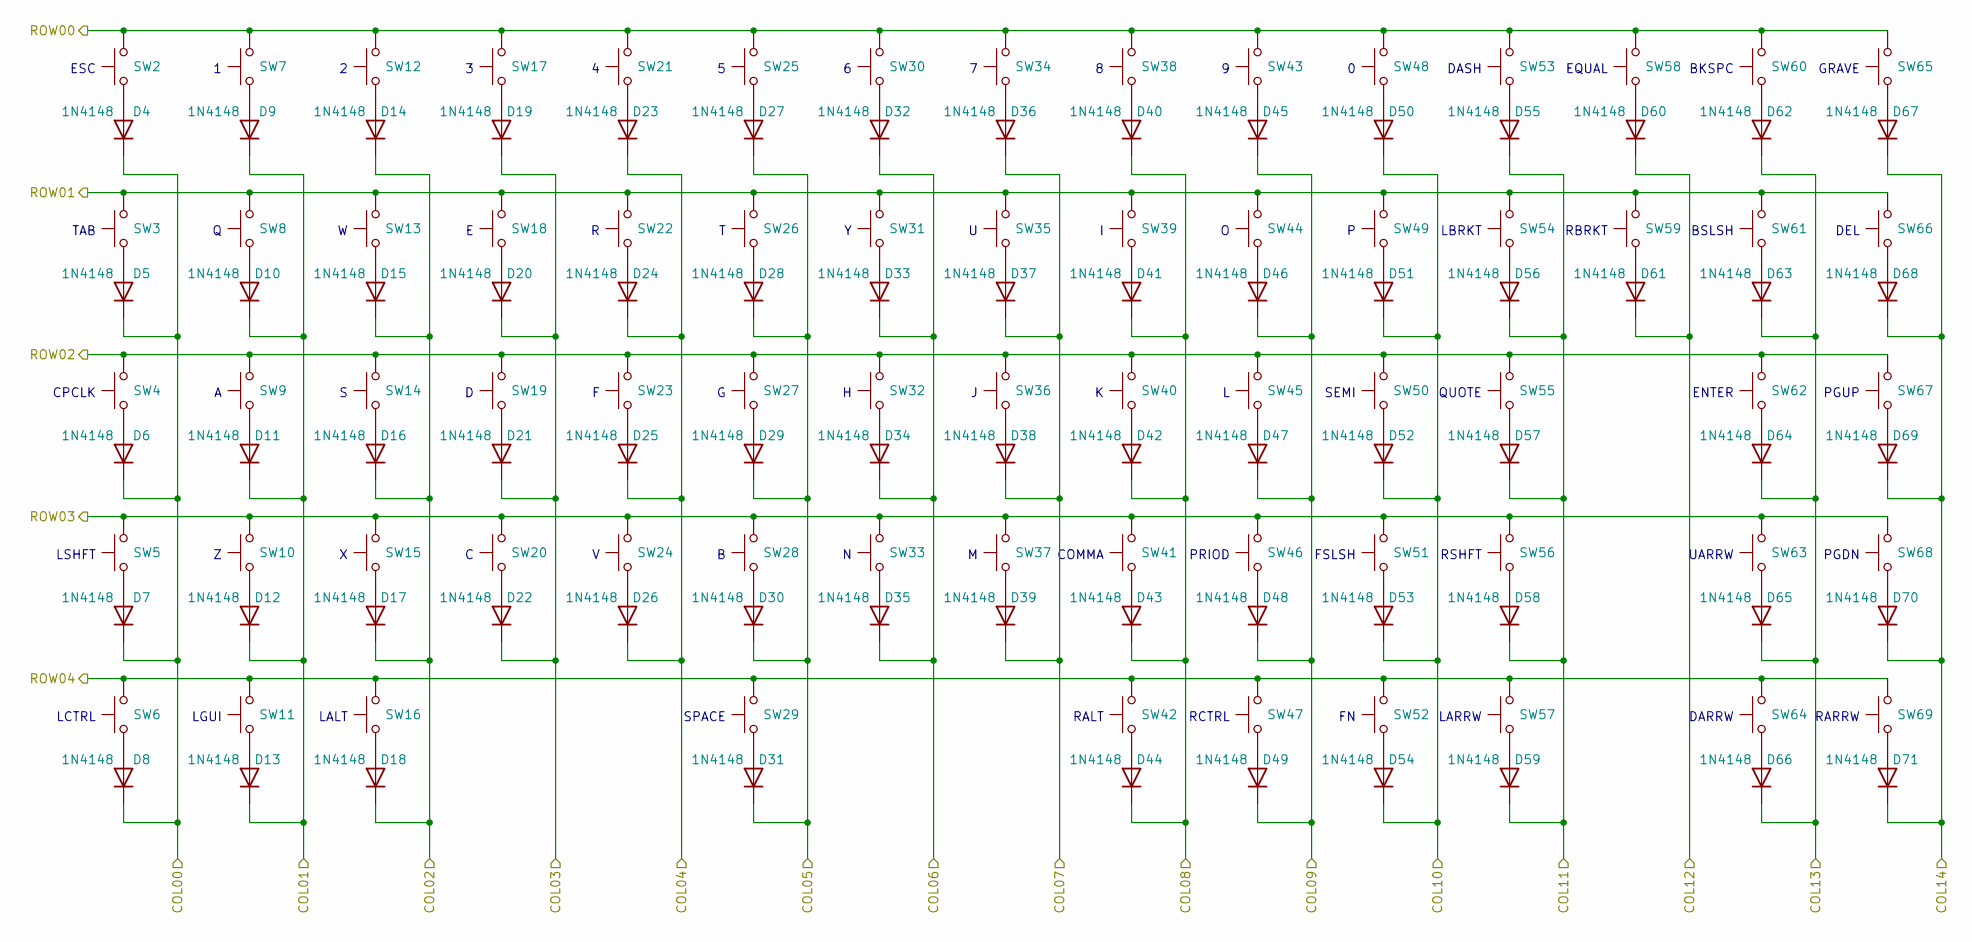
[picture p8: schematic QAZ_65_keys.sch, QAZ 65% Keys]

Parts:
D4, D5, D6, D7, D8, D9, D10, D11, D12, D13, D14, D15, D16, D17, D18, D19, D20, D21, D22, D23, D24, D25, D26, D27, D28, D29, D30, D31, D32, D33, D34, D35, D36, D37, D38, D39, D40, D41, D42, D43, D44, D45, D46, D47, D48, D49, D50, D51, D52, D53, D54, D55, D56, D57, D58, D59, D60, D61, D62, D63, D64, D65, D66, D67, D68, D69, D70, D71: 1N4148; D_DO-35_SOD27_P7.62mm_Horizontal
SW2, SW7, SW8, SW9, SW10, SW12, SW13, SW14, SW15, SW17, SW18, SW19, SW20, SW21, SW22, SW23, SW24, SW25, SW26, SW27, SW28, SW30, SW31, SW32, SW33, SW34, SW35, SW36, SW37, SW38, SW39, SW40, SW41, SW42, SW43, SW44, SW45, SW46, SW47, SW48, SW49, SW50, SW51, SW52, SW53, SW54, SW55, SW57, SW58, SW59, SW63, SW64, SW65, SW66, SW67, SW68, SW69: Cherry MX; SW_Cherry_MX_1.00u_PCB
SW3, SW61: Cherry MX; SW_Cherry_MX_1.50u_PCB
SW4, SW56: Cherry MX; SW_Cherry_MX_1.75u_PCB
SW5, SW62: Cherry MX; SW_Cherry_MX_2.25u_PCB
SW6, SW11, SW16: Cherry MX; SW_Cherry_MX_1.25u_PCB
SW29: Cherry MX; SW_Cherry_MX_6.25u_PCB
SW60: Cherry MX; SW_Cherry_MX_2.00u_PCB

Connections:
/QAZ Keys/COL00: D4.1 (K), D5.1 (K), D6.1 (K), D7.1 (K), D8.1 (K); also elsewhere on the board
/QAZ Keys/COL01: D9.1 (K), D10.1 (K), D11.1 (K), D12.1 (K), D13.1 (K); also elsewhere on the board
/QAZ Keys/COL02: D14.1 (K), D15.1 (K), D16.1 (K), D17.1 (K), D18.1 (K); also elsewhere on the board
/QAZ Keys/COL03: D19.1 (K), D20.1 (K), D21.1 (K), D22.1 (K); also elsewhere on the board
/QAZ Keys/COL04: D23.1 (K), D24.1 (K), D25.1 (K), D26.1 (K); also elsewhere on the board
/QAZ Keys/COL05: D27.1 (K), D28.1 (K), D29.1 (K), D30.1 (K), D31.1 (K); also elsewhere on the board
/QAZ Keys/COL06: D32.1 (K), D33.1 (K), D34.1 (K), D35.1 (K); also elsewhere on the board
/QAZ Keys/COL07: D36.1 (K), D37.1 (K), D38.1 (K), D39.1 (K); also elsewhere on the board
/QAZ Keys/COL08: D40.1 (K), D41.1 (K), D42.1 (K), D43.1 (K), D44.1 (K); also elsewhere on the board
/QAZ Keys/COL09: D45.1 (K), D46.1 (K), D47.1 (K), D48.1 (K), D49.1 (K); also elsewhere on the board
/QAZ Keys/COL10: D50.1 (K), D51.1 (K), D52.1 (K), D53.1 (K), D54.1 (K); also elsewhere on the board
/QAZ Keys/COL11: D55.1 (K), D56.1 (K), D57.1 (K), D58.1 (K), D59.1 (K); also elsewhere on the board
/QAZ Keys/COL12: D60.1 (K), D61.1 (K); also elsewhere on the board
/QAZ Keys/COL13: D62.1 (K), D63.1 (K), D64.1 (K), D65.1 (K), D66.1 (K); also elsewhere on the board
/QAZ Keys/COL14: D67.1 (K), D68.1 (K), D69.1 (K), D70.1 (K), D71.1 (K); also elsewhere on the board
/QAZ Keys/ROW00: SW2.2, SW7.2, SW12.2, SW17.2, SW21.2, SW25.2, SW30.2, SW34.2, SW38.2, SW43.2, SW48.2, SW53.2, SW58.2, SW60.2, SW65.2; also elsewhere on the board
/QAZ Keys/ROW01: SW3.2, SW8.2, SW13.2, SW18.2, SW22.2, SW26.2, SW31.2, SW35.2, SW39.2, SW44.2, SW49.2, SW54.2, SW59.2, SW61.2, SW66.2; also elsewhere on the board
/QAZ Keys/ROW02: SW4.2, SW9.2, SW14.2, SW19.2, SW23.2, SW27.2, SW32.2, SW36.2, SW40.2, SW45.2, SW50.2, SW55.2, SW62.2, SW67.2; also elsewhere on the board
/QAZ Keys/ROW03: SW5.2, SW10.2, SW15.2, SW20.2, SW24.2, SW28.2, SW33.2, SW37.2, SW41.2, SW46.2, SW51.2, SW56.2, SW63.2, SW68.2; also elsewhere on the board
/QAZ Keys/ROW04: SW6.2, SW11.2, SW16.2, SW29.2, SW42.2, SW47.2, SW52.2, SW57.2, SW64.2, SW69.2; also elsewhere on the board
unnamed: D4.2 (A), SW2.1
unnamed: D5.2 (A), SW3.1
unnamed: D6.2 (A), SW4.1
unnamed: D7.2 (A), SW5.1
unnamed: D8.2 (A), SW6.1
unnamed: D9.2 (A), SW7.1
unnamed: D10.2 (A), SW8.1
unnamed: D11.2 (A), SW9.1
unnamed: D12.2 (A), SW10.1
unnamed: D13.2 (A), SW11.1
unnamed: D14.2 (A), SW12.1
unnamed: D15.2 (A), SW13.1
unnamed: D16.2 (A), SW14.1
unnamed: D17.2 (A), SW15.1
unnamed: D18.2 (A), SW16.1
unnamed: D19.2 (A), SW17.1
unnamed: D20.2 (A), SW18.1
unnamed: D21.2 (A), SW19.1
unnamed: D22.2 (A), SW20.1
unnamed: D23.2 (A), SW21.1
unnamed: D24.2 (A), SW22.1
unnamed: D25.2 (A), SW23.1
unnamed: D26.2 (A), SW24.1
unnamed: D27.2 (A), SW25.1
unnamed: D28.2 (A), SW26.1
unnamed: D29.2 (A), SW27.1
unnamed: D30.2 (A), SW28.1
unnamed: D31.2 (A), SW29.1
unnamed: D32.2 (A), SW30.1
unnamed: D33.2 (A), SW31.1
unnamed: D34.2 (A), SW32.1
unnamed: D35.2 (A), SW33.1
unnamed: D36.2 (A), SW34.1
unnamed: D37.2 (A), SW35.1
unnamed: D38.2 (A), SW36.1
unnamed: D39.2 (A), SW37.1
unnamed: D40.2 (A), SW38.1
unnamed: D41.2 (A), SW39.1
unnamed: D42.2 (A), SW40.1
unnamed: D43.2 (A), SW41.1
unnamed: D44.2 (A), SW42.1
unnamed: D45.2 (A), SW43.1
unnamed: D46.2 (A), SW44.1
unnamed: D47.2 (A), SW45.1
unnamed: D48.2 (A), SW46.1
unnamed: D49.2 (A), SW47.1
unnamed: D50.2 (A), SW48.1
unnamed: D51.2 (A), SW49.1
unnamed: D52.2 (A), SW50.1
unnamed: D53.2 (A), SW51.1
unnamed: D54.2 (A), SW52.1
unnamed: D55.2 (A), SW53.1
unnamed: D56.2 (A), SW54.1
unnamed: D57.2 (A), SW55.1
unnamed: D58.2 (A), SW56.1
unnamed: D59.2 (A), SW57.1
unnamed: D60.2 (A), SW58.1
unnamed: D61.2 (A), SW59.1
unnamed: D62.2 (A), SW60.1
unnamed: D63.2 (A), SW61.1
unnamed: D64.2 (A), SW62.1
unnamed: D65.2 (A), SW63.1
unnamed: D66.2 (A), SW64.1
unnamed: D67.2 (A), SW65.1
unnamed: D68.2 (A), SW66.1
unnamed: D69.2 (A), SW67.1
unnamed: D70.2 (A), SW68.1
unnamed: D71.2 (A), SW69.1

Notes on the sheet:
LCTRL
ESC
TAB
CPCLK
LSHFT
DASH
EQUAL
BKSPC
GRAVE
LGUI
LALT
LBRKT
RBRKT
BSLSH
DEL
SEMI
QUOTE
ENTER
PGUP
COMMA
PRIOD
FSLSH
RCTRL
RSHFT
SPACE
RALT
LARRW
PGDN
RARRW
DARRW
UARRW

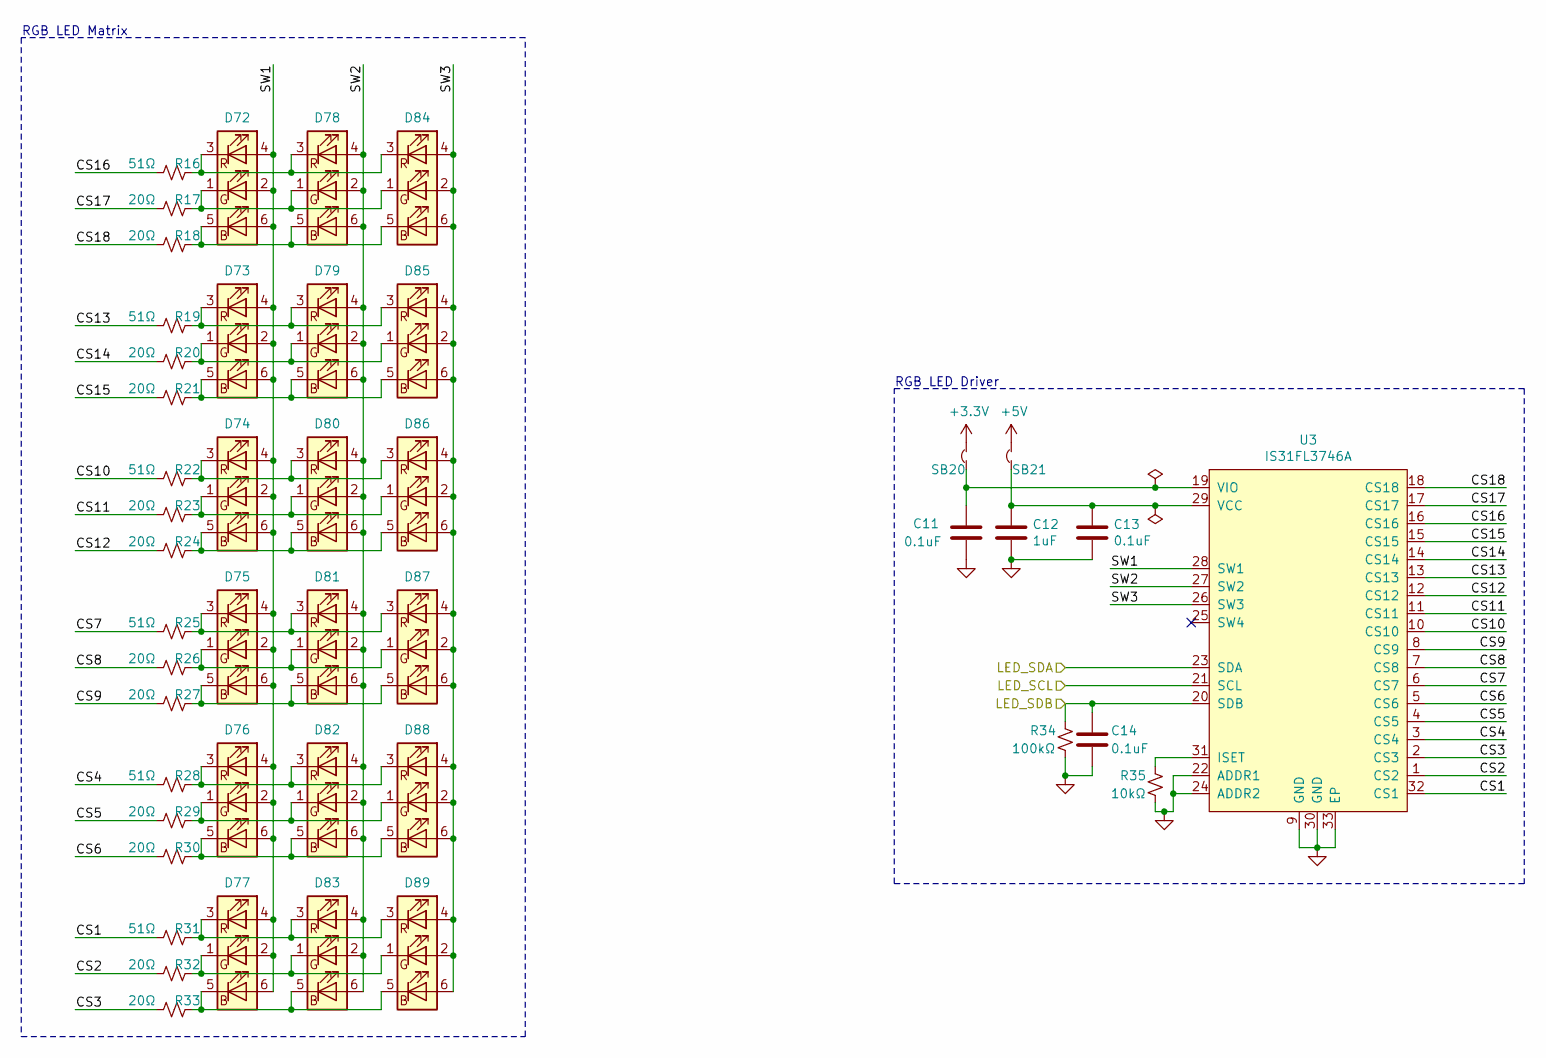
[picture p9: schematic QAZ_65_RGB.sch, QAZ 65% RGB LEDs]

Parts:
C11, C13, C14: 0.1uF; C_0603_1608Metric_Pad1.05x0.95mm_HandSolder
C12: 1uF; C_0603_1608Metric_Pad1.05x0.95mm_HandSolder
D72, D73, D74, D75, D76, D77, D78, D79, D80, D81, D82, D83, D84, D85, D86, D87, D88, D89: 19-337C_RSBHGHC-A88_4T; 0606_1616Metric_HS
R16, R19, R22, R25, R28, R31: 51Ω; R_0603_1608Metric_Pad1.05x0.95mm_HandSolder
R17, R18, R20, R21, R23, R24, R26, R27, R29, R30, R32, R33: 20Ω; R_0603_1608Metric_Pad1.05x0.95mm_HandSolder
R34: 100kΩ; R_0603_1608Metric_Pad1.05x0.95mm_HandSolder
R35: 10kΩ; R_0603_1608Metric_Pad1.05x0.95mm_HandSolder
SB20, SB21: SolderBridge; R_0603_1608Metric_Pad1.05x0.95mm_HandSolder
U3: IS31FL3746A; QFN-32-1EP_4x4mm_P0.4mm_EP2.9x2.9mm_HS

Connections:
+3V3: SB20.2; also elsewhere on the board
+5V: SB21.2; also elsewhere on the board
/LED_SCL: U3.21 (SCL); also elsewhere on the board
/LED_SDA: U3.23 (SDA); also elsewhere on the board
/LED_SDB: C14.2, R34.2, U3.20 (SDB); also elsewhere on the board
/QAZ RGB/CS1: R31.2, U3.32 (CS1)
/QAZ RGB/CS2: R32.2, U3.1 (CS2)
/QAZ RGB/CS3: R33.2, U3.2 (CS3)
/QAZ RGB/CS4: R28.2, U3.3 (CS4)
/QAZ RGB/CS5: R29.2, U3.4 (CS5)
/QAZ RGB/CS6: R30.2, U3.5 (CS6)
/QAZ RGB/CS7: R25.2, U3.6 (CS7)
/QAZ RGB/CS8: R26.2, U3.7 (CS8)
/QAZ RGB/CS9: R27.2, U3.8 (CS9)
/QAZ RGB/CS10: R22.2, U3.10 (CS10)
/QAZ RGB/CS11: R23.2, U3.11 (CS11)
/QAZ RGB/CS12: R24.2, U3.12 (CS12)
/QAZ RGB/CS13: R19.2, U3.13 (CS13)
/QAZ RGB/CS14: R20.2, U3.14 (CS14)
/QAZ RGB/CS15: R21.2, U3.15 (CS15)
/QAZ RGB/CS16: R16.2, U3.16 (CS16)
/QAZ RGB/CS17: R17.2, U3.17 (CS17)
/QAZ RGB/CS18: R18.2, U3.18 (CS18)
/QAZ RGB/SW1: D72.2, D72.4, D72.6, D73.2, D73.4, D73.6, D74.2, D74.4, D74.6, D75.2, D75.4, D75.6, D76.2, D76.4, D76.6, D77.2, D77.4, D77.6, U3.28 (SW1)
/QAZ RGB/SW2: D78.2, D78.4, D78.6, D79.2, D79.4, D79.6, D80.2, D80.4, D80.6, D81.2, D81.4, D81.6, D82.2, D82.4, D82.6, D83.2, D83.4, D83.6, U3.27 (SW2)
/QAZ RGB/SW3: D84.2, D84.4, D84.6, D85.2, D85.4, D85.6, D86.2, D86.4, D86.6, D87.2, D87.4, D87.6, D88.2, D88.4, D88.6, D89.2, D89.4, D89.6, U3.26 (SW3)
GND: C11.1, C12.1, C13.1, C14.1, R34.1, R35.1, U3.9 (GND), U3.22 (ADDR1), U3.24 (ADDR2), U3.30 (GND), U3.33 (EP); also elsewhere on the board
unnamed: C11.2, SB20.1, U3.19 (VIO)
unnamed: C12.2, C13.2, SB21.1, U3.29 (VCC)
unnamed: D72.1, D78.1, D84.1, R17.1
unnamed: D72.3, D78.3, D84.3, R16.1
unnamed: D72.5, D78.5, D84.5, R18.1
unnamed: D73.1, D79.1, D85.1, R20.1
unnamed: D73.3, D79.3, D85.3, R19.1
unnamed: D73.5, D79.5, D85.5, R21.1
unnamed: D74.1, D80.1, D86.1, R23.1
unnamed: D74.3, D80.3, D86.3, R22.1
unnamed: D74.5, D80.5, D86.5, R24.1
unnamed: D75.1, D81.1, D87.1, R26.1
unnamed: D75.3, D81.3, D87.3, R25.1
unnamed: D75.5, D81.5, D87.5, R27.1
unnamed: D76.1, D82.1, D88.1, R29.1
unnamed: D76.3, D82.3, D88.3, R28.1
unnamed: D76.5, D82.5, D88.5, R30.1
unnamed: D77.1, D83.1, D89.1, R32.1
unnamed: D77.3, D83.3, D89.3, R31.1
unnamed: D77.5, D83.5, D89.5, R33.1
unnamed: R35.2, U3.31 (ISET)

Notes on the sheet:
RGB LED Driver
RGB LED Matrix

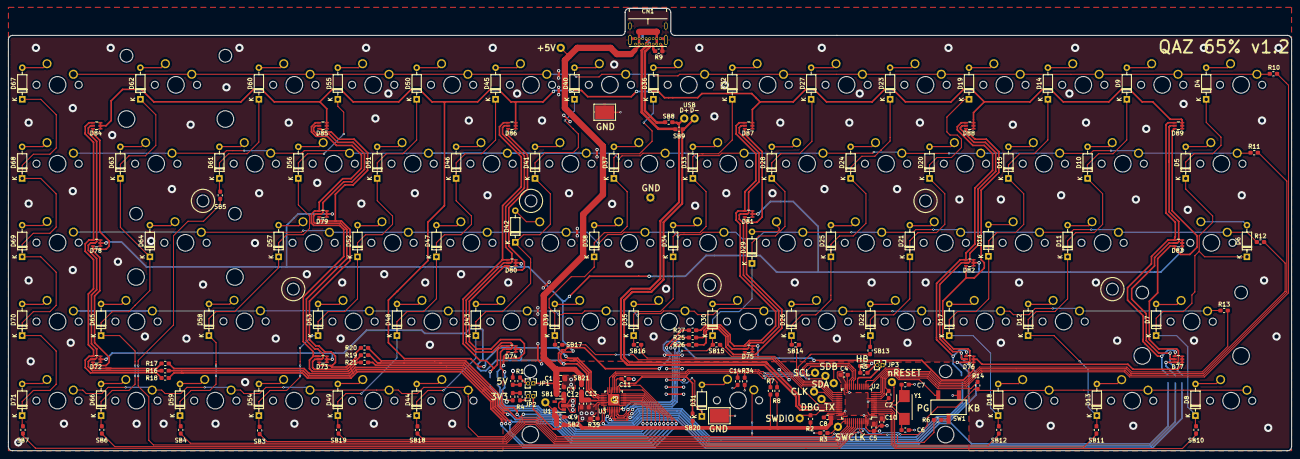
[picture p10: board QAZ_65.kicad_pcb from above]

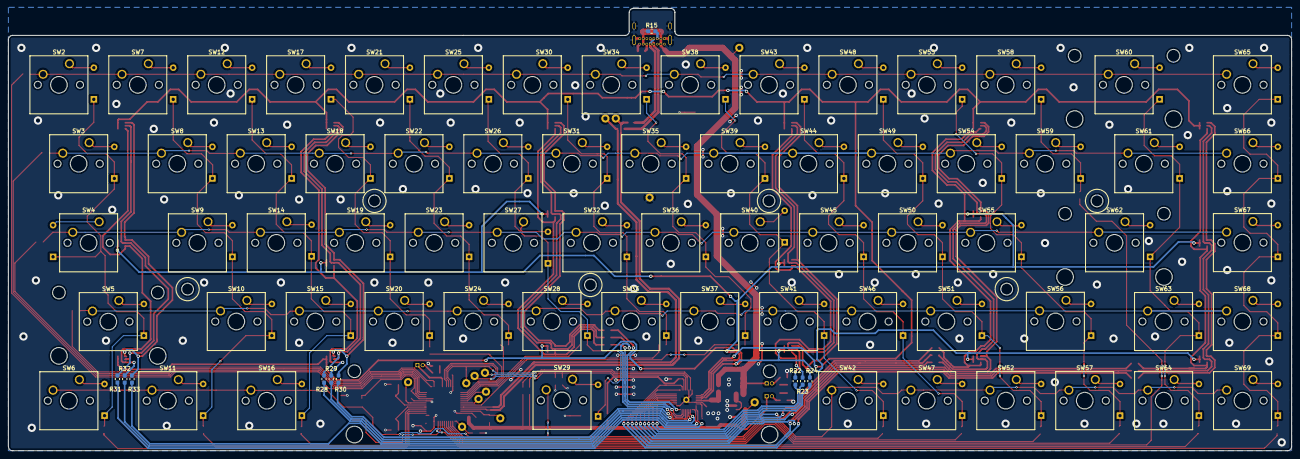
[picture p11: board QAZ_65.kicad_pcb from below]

Board: 2 copper layers, 309.0 x 106.5 mm, 257 parts (78 on the bottom side), 180 nets.

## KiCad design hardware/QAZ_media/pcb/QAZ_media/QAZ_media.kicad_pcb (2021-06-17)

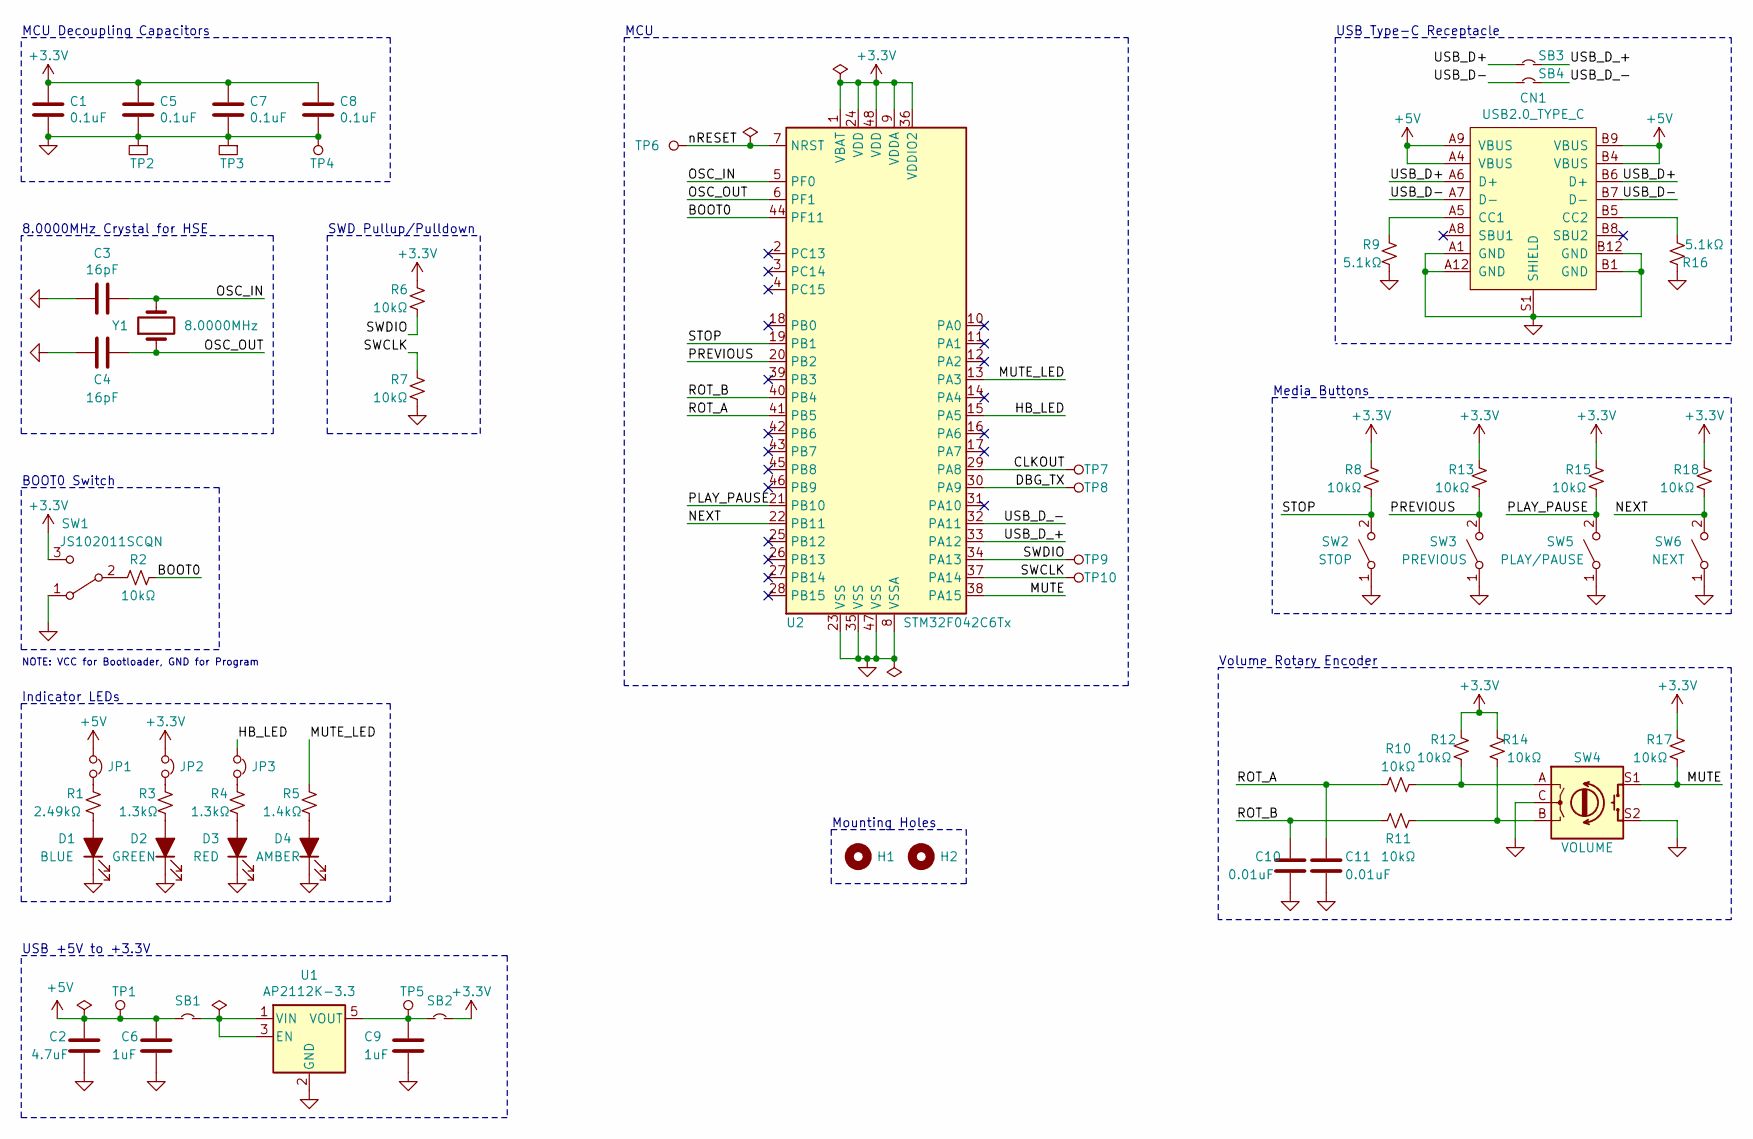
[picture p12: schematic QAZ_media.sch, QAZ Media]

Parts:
C1, C5, C7, C8: 0.1uF; C_0603_1608Metric_Pad1.05x0.95mm_HandSolder
C2: 4.7uF; C_0805_2012Metric_Pad1.15x1.40mm_HandSolder
C3, C4: 16pF; C_0603_1608Metric_Pad1.05x0.95mm_HandSolder
C6, C9: 1uF; C_0603_1608Metric_Pad1.05x0.95mm_HandSolder
C10, C11: 0.01uF; C_0603_1608Metric_Pad1.05x0.95mm_HandSolder
CN1: USB2.0_TYPE_C; USB_C_GCT_USB4085
D1: BLUE; R_0603_1608Metric_Pad1.05x0.95mm_HandSolder
D2: GREEN; R_0603_1608Metric_Pad1.05x0.95mm_HandSolder
D3: RED; R_0603_1608Metric_Pad1.05x0.95mm_HandSolder
D4: AMBER; PinHeader_1x02_P2.54mm_Vertical
H1, H2: MountingHole; 4-40_NPTH
JP1, JP2, JP3: Jumper_NC_Small; PinHeader_1x02_P1.27mm_Vertical
R1: 2.49kΩ; R_0603_1608Metric_Pad1.05x0.95mm_HandSolder
R2, R6, R7, R8, R10, R11, R12, R13, R14, R15, R17, R18: 10kΩ; R_0603_1608Metric_Pad1.05x0.95mm_HandSolder
R3, R4: 1.3kΩ; R_0603_1608Metric_Pad1.05x0.95mm_HandSolder
R5: 1.4kΩ; R_0603_1608Metric_Pad1.05x0.95mm_HandSolder
R9, R16: 5.1kΩ; R_0603_1608Metric_Pad1.05x0.95mm_HandSolder
SB1, SB2, SB3, SB4: SolderBridge; R_0603_1608Metric_Pad1.05x0.95mm_HandSolder
SW1: JS102011SCQN; JS102011SCQN_SPDT
SW2: STOP; NCA2
SW3: PREVIOUS; NCA2
SW4: VOLUME; RotaryEncoder_Alps_EC11E-Switch_Vertical_H20mm
SW5: PLAY/PAUSE; NCA2
SW6: NEXT; NCA2
TP1, TP4, TP5, TP6, TP7, TP8, TP9, TP10: TestPoint_Thruhole_0.7mm
TP2, TP3: TestPoint_SMD_1812; TestPoint_SMD_1812_HS
U1: AP2112K-3.3; SOT-23-5
U2: STM32F042C6Tx; LQFP-48_7x7mm_P0.5mm
Y1: 8.0000MHz; Crystal_SMD_Abracon_ABM7-2Pin_6.0x3.5mm_HS

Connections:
+3V3: C1.1, C5.1, C7.1, C8.1, JP2.1, R6.1, R8.1, R12.1, R13.1, R14.1, R15.1, R17.1, R18.1, SB2.2, SW1.3 (C), U2.1 (VBAT), U2.9 (VDDA), U2.24 (VDD), U2.36 (VDDIO2), U2.48 (VDD)
+5V: C2.1, C6.1, CN1.A4 (VBUS), CN1.A9 (VBUS), CN1.B4 (VBUS), CN1.B9 (VBUS), JP1.1, SB1.1, TP1.1
/BOOT0: R2.1, U2.44 (PF11)
/CLKOUT: TP7.1, U2.29 (PA8)
/DBG_TX: TP8.1, U2.30 (PA9)
/HB_LED: JP3.1, U2.15 (PA5)
/MUTE: R17.2, SW4.S1, U2.38 (PA15)
/MUTE_LED: R5.1, U2.13 (PA3)
/NEXT: R18.2, SW6.2 (B), U2.22 (PB11)
/OSC_IN: C3.1, U2.5 (PF0), Y1.2
/OSC_OUT: C4.1, U2.6 (PF1), Y1.1
/PLAY_PAUSE: R15.2, SW5.2 (B), U2.21 (PB10)
/PREVIOUS: R13.2, SW3.2 (B), U2.20 (PB2)
/ROT_A: C11.1, R10.1, U2.41 (PB5)
/ROT_B: C10.1, R11.1, U2.40 (PB4)
/STOP: R8.2, SW2.2 (B), U2.19 (PB1)
/SWCLK: R7.1, TP10.1, U2.37 (PA14)
/SWDIO: R6.2, TP9.1, U2.34 (PA13)
/USB_D+: CN1.A6 (D+), CN1.B6 (D+), SB3.1
/USB_D-: CN1.A7 (D-), CN1.B7 (D-), SB4.1
/USB_D_+: SB3.2, U2.33 (PA12)
/USB_D_-: SB4.2, U2.32 (PA11)
/nRESET: TP6.1, U2.7 (NRST)
GND: C1.2, C2.2, C3.2, C4.2, C5.2, C6.2, C7.2, C8.2, C9.2, C10.2, C11.2, CN1.A1 (GND), CN1.A12 (GND), CN1.B1 (GND), CN1.B12 (GND), CN1.S1 (SHIELD), D1.1 (K), D2.1 (K), D3.1 (K), D4.1 (K), R7.2, R9.2, R16.1, SW1.1 (A), SW2.1 (A), SW3.1 (A), SW4.C, SW4.S2, SW5.1 (A), SW6.1 (A), TP2.1, TP3.1, TP4.1, U1.2 (GND), U2.8 (VSSA), U2.23 (VSS), U2.35 (VSS), U2.47 (VSS)
unnamed: C9.1, SB2.1, TP5.1, U1.5 (VOUT)
unnamed: CN1.A5 (CC1), R9.1
unnamed: CN1.B5 (CC2), R16.2
unnamed: D1.2 (A), R1.2
unnamed: D2.2 (A), R3.2
unnamed: D3.2 (A), R4.2
unnamed: D4.2 (A), R5.2
unnamed: JP1.2, R1.1
unnamed: JP2.2, R3.1
unnamed: JP3.2, R4.1
unnamed: R2.2, SW1.2 (B)
unnamed: R10.2, R12.2, SW4.A
unnamed: R11.2, R14.2, SW4.B
unnamed: SB1.2, U1.1 (VIN), U1.3 (EN)

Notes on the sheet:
MCU Decoupling Capacitors
8.0000MHz Crystal for HSE
BOOT0 Switch
NOTE: VCC for Bootloader, GND for Program
Indicator LEDs
USB +5V to +3.3V
SWD Pullup/Pulldown
MCU
USB Type-C Receptacle
Media Buttons
Volume Rotary Encoder
Mounting Holes

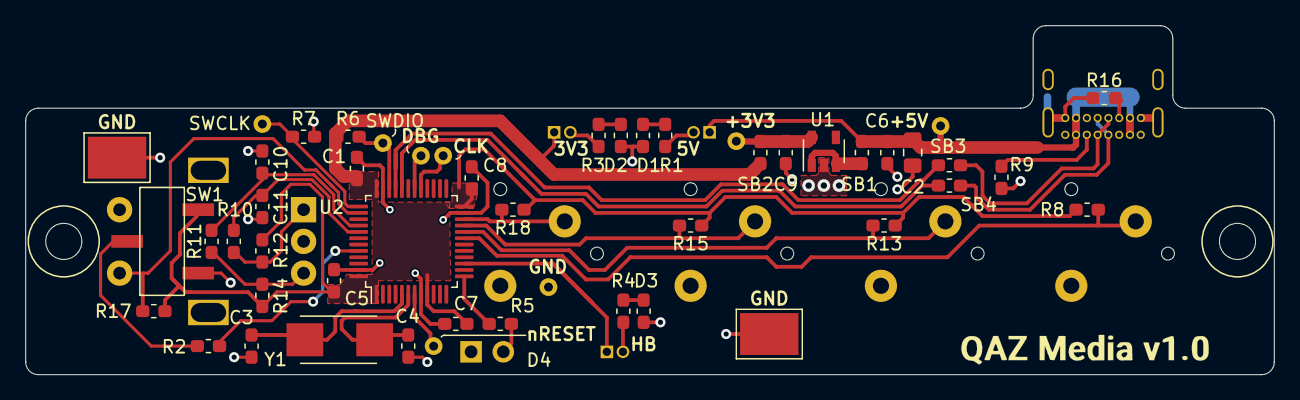
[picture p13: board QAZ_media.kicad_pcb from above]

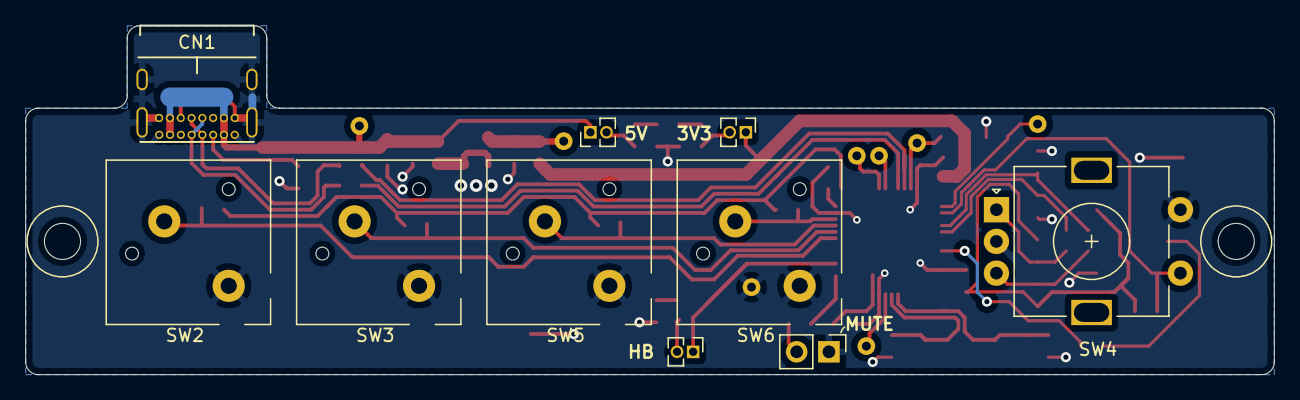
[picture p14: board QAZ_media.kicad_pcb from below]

Board: 2 copper layers, 98.4 x 27.5 mm, 62 parts (10 on the bottom side), 38 nets.

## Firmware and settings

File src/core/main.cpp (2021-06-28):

/**
 * @file      main.cpp
 * @brief     QAZ init and loop entry
 *
 * @author    Anthony Needles
 * @date      2020/10/12
 * @copyright (c) 2020 Anthony Needles. GNU GPL v3 (see LICENSE)
 *
 * The QAZ Keyboard project.
 *
 * https://github.com/anthonyneedles/QAZ
 */

#include "bsp/bsp.hpp"
#include "core/clock.hpp"
#include "core/time_slice.hpp"
#include "flash/persist.hpp"
#include "util/debug.hpp"
#include "util/hb.hpp"

int main(void)
{
    // inits - specifically ordered
    clock::init();
    debug::init();
    timeslice::init();
    persist::init();
    heartbeat::init();

    // inits - bsp specified
    bsp::init();

    // enter the loop - no return
    timeslice::enter_loop();

    while (1) {}
}

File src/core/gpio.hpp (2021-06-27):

/**
 * @file      gpio.hpp
 * @brief     GPIO Control API
 *
 * @author    Anthony Needles
 * @date      2021/01/01
 * @copyright (c) 2020 Anthony Needles. GNU GPL v3 (see LICENSE)
 *
 * Holds GPIO control API, for controlling GPIO pins in an object-oriented method.
 */

#ifndef CORE_GPIO_HPP_
#define CORE_GPIO_HPP_

#include "util/bitop.hpp"
#include "stm32f0xx.h"  // NOLINT

/**
 * @brief GPIO base namespace
 *
 * This namespace holds enums for gpio pin config options, as well as the methods to set those
 * configs, control output, etc.
 */
namespace gpio {

/// Port enums set to the base address for port registers
enum Port : uint32_t {
    #ifdef GPIOA_BASE
    A = GPIOA_BASE,
    #endif
    #ifdef GPIOB_BASE
    B = GPIOB_BASE,
    #endif
    #ifdef GPIOC_BASE
    C = GPIOC_BASE,
    #endif
    #ifdef GPIOD_BASE
    D = GPIOD_BASE,
    #endif
    #ifdef GPIOE_BASE
    E = GPIOE_BASE,
    #endif
    #ifdef GPIOF_BASE
    F = GPIOF_BASE,
    #endif
    #ifdef GPIOG_BASE
    G = GPIOG_BASE,
    #endif
    #ifdef GPIOH_BASE
    H = GPIOH_BASE,
    #endif
};

/// Pins for each gpio port (may need to be port-specific?)
enum Pin : uint32_t {
    PIN_0  =  0,
    PIN_1  =  1,
    PIN_2  =  2,
    PIN_3  =  3,
    PIN_4  =  4,
    PIN_5  =  5,
    PIN_6  =  6,
    PIN_7  =  7,
    PIN_8  =  8,
    PIN_9  =  9,
    PIN_10 = 10,
    PIN_11 = 11,
    PIN_12 = 12,
    PIN_13 = 13,
    PIN_14 = 14,
    PIN_15 = 15,
};

/// Modes in MODER register
enum Mode : uint32_t {
    INPUT  = 0x0,
    OUTPUT = 0x1,
    ALTFN  = 0x2,
    ANALOG = 0x3,
};

/// Pulls in PUPDR register
enum Pull : uint32_t {
    NO_PULL    = 0x0,
    PULL_UP    = 0x1,
    PULL_DOWN  = 0x2,
};

/// Output types in OTYPER register
enum OutputType : uint32_t {
    PUSH_PULL  = 0x0,
    OPEN_DRAIN = 0x1,
};

/// Alternate functions in AFL/AFH registers
enum AltFn : uint32_t {
    ALTFN_0 = 0x0,
    ALTFN_1 = 0x1,
    ALTFN_2 = 0x2,
    ALTFN_3 = 0x3,
    ALTFN_4 = 0x4,
    ALTFN_5 = 0x5,
    ALTFN_6 = 0x6,
    ALTFN_7 = 0x7,
};

/// Output speeds in OSPEEDR register
enum OutputSpeed : uint32_t {
    LOW_SPEED  = 0x0,
    MED_SPEED  = 0x1,
    HIGH_SPEED = 0x3,
};

/// Output/input states in ODR/IDR registers
enum PinState : uint32_t {
    CLR = 0x0,
    SET = 0x1,
};

/// What type of active config does an input have
enum InputConfig {
    ACTIVE_LOW,
    ACTIVE_HIGH,
};

/// Identification structure for each gpio pin
struct Id {
    Port port;
    Pin  pin;
};

/**
 * @brief Convert template port value to port structure
 *
 * The template `TPort` input is the address of the GPIO structure defined in the CMSIS header. This
 * struct maps the GPIO registers for each port. This method will convert this address to the
 * structure.
 *
 * @param[in] id    identification for gpio
 * @return    gpio  structure pointer
 */
inline volatile GPIO_TypeDef *regs(Id id)
{
    return reinterpret_cast<GPIO_TypeDef *>(id.port);
}

/**
 * @brief Enable the given port clock
 *
 * Unfortunately, there doesn't seem to be a good way to do this. Since pin clocks are usually only
 * set upon initialization, this is good enough.
 *
 * @param[in] id  identification for gpio
 */
inline void enable_port_clock(Id id)
{
    bitop::set_msk(RCC->AHBENR,
        #ifdef GPIOA
        (regs(id) == GPIOA) ? RCC_AHBENR_GPIOAEN :
        #endif
        #ifdef GPIOB
        (regs(id) == GPIOB) ? RCC_AHBENR_GPIOBEN :
        #endif
        #ifdef GPIOC
        (regs(id) == GPIOC) ? RCC_AHBENR_GPIOCEN :
        #endif
        #ifdef GPIOD
        (regs(id) == GPIOD) ? RCC_AHBENR_GPIODEN :
        #endif
        #ifdef GPIOE
        (regs(id) == GPIOE) ? RCC_AHBENR_GPIOEEN :
        #endif
        #ifdef GPIOF
        (regs(id) == GPIOF) ? RCC_AHBENR_GPIOFEN :
        #endif
        #ifdef GPIOG
        (regs(id) == GPIOG) ? RCC_AHBENR_GPIOGEN :
        #endif
        #ifdef GPIOH
        (regs(id) == GPIOH) ? RCC_AHBENR_GPIOHEN :
        #endif
        0);
}

/**
 * @brief Set the GPIO mode
 *
 * A GPIO can be either an input, output, alternate function, or analog.
 *
 * @param[in] id    identification for gpio
 * @param[in] mode  the mode option to set
 */
inline void set_mode(Id id, Mode mode)
{
    bitop::update_msk(regs(id)->MODER, 0x3u << id.pin*2, mode << id.pin*2);
}

/**
 * @brief Set the GPIO pull
 *
 * A GPIO can have a pull up, pull down, or neither.
 *
 * @param[in] id    identification for gpio
 * @param[in] pull  the pull option to set
 */
inline void set_pull(Id id, Pull pull)
{
    bitop::update_msk(regs(id)->PUPDR, 0x3u << id.pin*2, pull << id.pin*2);
}

/**
 * @brief Set the GPIO output type
 *
 * A GPIO can be set to push/pull or open drain output.
 *
 * @param[in] id    identification for gpio
 * @param[in] type  the output type option to set
 */
inline void set_output_type(Id id, OutputType type)
{
    bitop::update_msk(regs(id)->OTYPER, 0x3u << id.pin*2, type << id.pin*2);
}
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

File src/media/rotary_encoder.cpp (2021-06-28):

/**
 * @file      rotary_encoder.cpp
 * @brief     Implements reading of rotary encoder
 *
 * @author    Anthony Needles
 * @date      2021/06/26
 * @copyright (c) 2020 Anthony Needles. GNU GPL v3 (see LICENSE)
 *
 * Rotary encoders can be read with the timer peripherals, when put into encoder mode.
 *
 * TIM3 is used to read the rotary encoder, using TIM3 CH1 and CH2. The CNT register is reset after
 * each read, so the value we read is a relative change in position, rather than an absolute one.
 */

#include "media/rotary_encoder.hpp"

#include "bsp/bsp.hpp"
#include "core/gpio.hpp"
#include "core/time_slice.hpp"
#include "usb/consumer_hid.hpp"
#include "util/bitop.hpp"
#include "util/debug.hpp"
#include "stm32f0xx.h"  // NOLINT

namespace {

/// Task fuction will execute every 20ms
constexpr unsigned ROT_ENC_TASK_PERIOD_MS = 20;

}  // namespace

/**
 * @brief Initializes rotary encoder reading via TIM3
 *
 * We read our rotary encoder using TIM3 CH1 and CH2. TIM3 is put into encoder mode and set to
 * increment on both TI1 and TI2 (CH1 and CH2 input).
 */
void rotary_encoder::init(void)
{
    // enable clock to TIM3 peripheral
    bitop::set_msk(RCC->APB1ENR, RCC_APB1ENR_TIM3EN);

    // set both rotary encoder channels to ALTFN1 (TIM3_CH1/TIM3_CH2)
    gpio::enable_port_clock(bsp::ROT_ENC_A);
    gpio::set_mode(bsp::ROT_ENC_A, gpio::ALTFN);
    gpio::set_altfn(bsp::ROT_ENC_A, gpio::ALTFN_1);
    gpio::enable_port_clock(bsp::ROT_ENC_B);
    gpio::set_mode(bsp::ROT_ENC_B, gpio::ALTFN);
    gpio::set_altfn(bsp::ROT_ENC_B, gpio::ALTFN_1);

    // set our timer in encoder mode, counting on input 1/2 (SMS = 0b001)
    bitop::update_msk(TIM3->SMCR,  TIM_SMCR_SMS_Msk,   TIM_SMCR_SMS_0 | TIM_SMCR_SMS_1);

    // input channel 1/2 is mapped to encoder incoder input 1/2
    bitop::update_msk(TIM3->CCMR1, TIM_CCMR1_CC1S_Msk, TIM_CCMR1_CC1S_0);
    bitop::update_msk(TIM3->CCMR1, TIM_CCMR1_CC2S_Msk, TIM_CCMR1_CC2S_0);

    // invert just ch1, so we count up when turning clockwise
    bitop::update_msk(TIM3->CCER,  TIM_CCER_CC1P_Msk | TIM_CCER_CC1NP, TIM_CCER_CC1P);

    // we count from 0 - 0xFFFF, so -32768 to 32767 if we interpret the count as an int16
    TIM3->ARR = 0xFFFF;

    // enable the timer
    bitop::set_msk(TIM3->CR1, TIM_CR1_CEN);

    auto stat2 = timeslice::register_task(ROT_ENC_TASK_PERIOD_MS, rotary_encoder::task);
    DBG_ASSERT(stat2 == timeslice::SUCCESS);

    debug::puts("Initialized: Rotary Encoder\r\n");
}

/**
 * @brief Read our encoder input
 *
 * The count register will hold a value that corresponds with the movement since the last sample,
 * since we write the count register with 0 after every sample.
 *
 * Positive values correspond with clockwise rotation, and negative with counter clockwise rotation.
 */
void rotary_encoder::task(void)
{
    int16_t rotation_val = static_cast<int16_t>(TIM3->CNT);
    if (rotation_val > 0) {
        consumer_hid::set_vol_up();
    } else if (rotation_val < 0) {
        consumer_hid::set_vol_down();
    }
    TIM3->CNT = 0;
}

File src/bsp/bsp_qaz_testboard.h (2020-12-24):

/**
 * @file      bsp_qaz_testboard.h
 * @brief     BSP for the QAZ testboard
 *
 * @author    Anthony Needles
 * @date      2020/12/20
 * @copyright (c) 2020 Anthony Needles. GNU GPL v3 (see LICENSE)
 *
 * Definitions specfic to the QAZ testboard.
 */

#ifndef BSP_BSP_QAZ_TESTBOARD_H_
#define BSP_BSP_QAZ_TESTBOARD_H_

// output GPIO ports. each column has:
//     port - the port (A, B, C, D, ...)
//     pin  - the pin number
#define COL_TABLE(COL) \
    COL(GPIOA, 15) \
    COL(GPIOB,  3) \
    COL(GPIOB,  6)

// input GPIO rows. each row has:
//     port - the port (A, B, C, D, ...)
//     pin  - the pin number
#define ROW_TABLE(ROW) \
    ROW(GPIOB,  4) \
    ROW(GPIOB,  5) \
    ROW(GPIOB,  7)

// base key symbol table
//     symbol - the symbol for the key. must match with HID_USAGE_KEYBOARD_* define
#define BASE_TABLE(K) \
    K(FN)    K(2)     K(3)     \
    K(4)     K(5)     K(6)     \
    K(7)     K(8)     K(9)

// fn key symbol table - for when the FN key is pressed
//     symbol - the symbol for the key. must match with HID_USAGE_KEYBOARD_* define
#define FN_TABLE(K) \
    K(FN)    K(2)     K(3)     \
    K(4)     K(COLOR) K(BRTUP) \
    K(7)     K(PROF)  K(BRTDN)

// which keys get a callback function
#define CALLBACK_KEY_TABLE(K) \
    K(BRTUP) K(BRTDN) K(COLOR) K(PROF)

// HB driving GPIO port
#define HB_LED_PORT GPIOB
#define HB_LED_PIN  13

// RGB LED enable pin
#define LED_EN_PORT GPIOB
#define LED_EN_PIN  2

// USART used for sending debug messages
#define DEBUG_UART USART1

// I2C used for talking to the LED controller
#define RGB_LED_I2C I2C1

#endif  // BSP_BSP_QAZ_TESTBOARD_H_

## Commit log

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2020-09-27 testboard: sch/pcb design for test board
    The QAZ Test Board will be used for checkout hardware and development of
    software. It features a 3x3 switch matrix, 1 RGB LED (w/ driver), SWD
    connection, debug UART connection, 5V to 3.3V regulator, USB Type-C
    connector, external crystal, STM32F042K6.
    [QAZ_externals.sch, QAZ_numpad_BOM.xlsx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]
2020-10-13 testboard: added bare-bones program sw
    This program serves as a basic checkout of the QAZ Test Board. It
    initializes the clock, the timeslice loop, and toggles the HB LED at
    1Hz.
2020-10-16 testboard: added debug uart
    Since using printf would require too much memory, DbgPrintf was defined
    as an alternative. This works very similar, but without some features.
    It will print over the debug uart USART1 @ PA8.
    Using assert would also require too much memory, so DBG_ASSERT was
    defined to give the same functionality. If the expression is false, then
    the context/expression is printed and the program halts.
    All of the printf/assert functionality will only do anything if
    BUILD_TYPE=DEBUG in the top level Makefile, allowing a much smaller code
    size when building for RELEASE.
    [clock.c, debug.c, hb.c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]
2020-10-16 testboard: added key matrix scanning
    Added key matrix scanning task. This allows reading of keypresses. Each
    column is Z until key scanning, they each column drives GND. Since
    each row is pulled to VCC, if a button is pressed, then the row will be
    driven the GND.
2020-10-18 testboard: add i2c module
    Added i2c module for driving I2C1. This will be used for communicating
    with the RGB LED driver.
2020-10-18 rgb_led: rgb led breakout board
    Designed RGB LED breakout board since the LED driver layout on the test
    board was incorrect. This is made to fit directly over the test board,
    connected via headers to TP9, TP11, and TP10.
    [QAZ_rgb_led_breakoutboard-B_Cu.gbr, QAZ_rgb_led_breakoutboard-B_Mask.gbr, QAZ_rgb_led_breakoutboard-B_SilkS.gbr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]
2020-10-31 rgb_led: adding rgb led driver
    Adding RGB LED driver that will utilize the I2C driver to communicate
    with the LP5009 LED driver. The driver is put into bank mode, which
    means that all LEDs are driven with the same values. API gives functions
    to set the brightness and color.
2020-10-31 rgb_led: added key buffer functionality
    Added functionality for key matrix key buffering, specifically two
    distinct ways to read keys:
    1. All keys currently pressed get sorted based on FN key state,
    and put into a buffer. This is for USB, eventually.
    2. Specified callback keys have their callbacks called ONCE PER PRESS.
    This is useful for things like changing LED color, brightness, etc.
    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
2020-11-16 qaz-65: added schematic, layout for QAZ 65%
    [QAZ_65-B_Cu.gbr, QAZ_65-B_Mask.gbr, QAZ_65-B_SilkS.gbr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]
2020-11-20 layers: v0 -> v1
    The layers were flipped horizontally so the opening is on the correct
    side. Plate layer space stabilizer cutout was too wide. Added 'v1'
    raster to top left corner.
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2020-11-26 usb: finally past enumeration, sending reports
    Finally got the device full enumerated and sending reports to the host.
    Since the device is defined as a mouse, we are sending cursor move
    reports, which successfully occur on the pc.
    The problem was not realizing that in the EP_REG macro I was incremented
    double the amount I wanted because of pointer arithmetic.
    Now, we can fine tune our actual keyboard report descriptor and start
    sending it based on key presses.
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2020-12-21 uart: split debug/uart
    In an effor to further modualize source files, the UART portions of the
    debug module were moved to their own separate file set (which itself is
    located in the comms/ subdir).
    Also fixed some indentation issues.
    [debug.c, i2c.c, key_matrix.c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]
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2020-12-24 qaz v1.1: fixes going from v1.0->v1.1
    Changed from individual pull up/down on BOOT0 MCU pin to switch that can
    easily change from one to the other (without soldering). This is
    required for programming over USB DFU.
    Fixed RESET switch, pins were flipped on part layout.
    [QAZ_65.kicad_pcb, QAZ_65.sch, QAZ_65_1v0_BOM.xlsx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]
2020-12-24 logo: added new qaz logo to doxygen
    Also updated Doxyfile with relative paths and started tracking the doc
    folder (with media subfolder). The doxygen subfolder is where the
    doxygen output goes (and is untracked).
    Also created silkscreen component from the logo and added to PCB
    [QAZ_65.kicad_pcb]
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2021-01-03 cpp: gpio changes
    The previous implementation of the GPIOBase class would not work well
    with the implementation of the key matrix (in it's current state). So
    the new GPIO struct just contains the GPIO modifier methods, which take
    an ID for each gpio.
    The resultant memory usage is unchanged.
    [bsp_qaz_65.hpp, clock.cpp, gpio.hpp]
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2021-01-06 cpp: usb hid reenabled
    Incorrectly changed a cast which broke USB. Working now.
    [main.cpp]
2021-01-09 cpp: 'inline'd constexpr global variables
    This doesn't change much for this project due to the optimization level.
    Without '-02' each translation unit that includes a header with
    constexpr constants will create a copy for each TU (internal linkage),
    since constexp does not imply inline for 'global' variables. Thus,
    inline needs to be explicitly given.
    [bsp_qaz_65.hpp, clock.cpp, i2c.cpp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]
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2021-01-10 cpp: no more std:: qualifying fixed width types
    Writing std::uint* is stupid for embedded systems where it is so
    prevalent to use fixed width types.
    [i2c.cpp, uart.cpp]
2021-01-20 Makefile: added LTO, reduced verbosity
    Reduced makefile verbosity. Moved common cxx/c flags.
    Added different optimizations based on BUILD_TYPE. RELEASE now links
    with link time optimizations, which results in the requirement that
    the startup object file must be before any object file that implements
    an ISR, since all ISRs are declared weak in the startup file.
    Added some fixes based on -pedantic. Tried to refactor integer literal
    conventions: all hex letters uppercase, suffixes lowercase.
    [gpio.hpp, i2c.cpp]
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2021-04-18 usb: hardcoded fixes
    Removed hardware delays which caused issues depending on the host.
    The fixes are hardcoded, and a larger structural change in the usb
    driver is needed to fully resolve the issues.
2021-04-24 usb: c++-ize usb driver
    Refactor/move around some things in the USB driver to make more
    consistent with the C++ style of the reset of the project.
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2021-05-30 led-breakout: adding IS31FL3732A breakout board
    In the next revision of the QAZ 65 board, the underglow will be supplied
    by an led matrix driver, allowing more leds and "spreading" the light
    out.
    [QAZ_IS31FL3746A_breakoutboard-B_Cu.gbr, QAZ_IS31FL3746A_breakoutboard-B_Mask.gbr, QAZ_IS31FL3746A_breakoutboard-B_SilkS.gbr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]
2021-05-30 fixes: various fixes
    Exclude CMSIS from doxygen/clint.
    Also make doxygen fixes, added size print for executable, fix all
    target.
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2021-05-30 QAZ 65% v1.1: updating from v1.0
    closes #5
    closes #3
    QAZ 65% v1.1:
    - Switch for BOOT (PG for booting into bootloader tor ProGram the
    board, KB for booting into KeyBoard)
    - New RGB driver IC, which allows driving RGB LEDS in a grid format
    [QAZ_65-B_Cu.gbr, QAZ_65-B_Mask.gbr, QAZ_65-B_SilkS.gbr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]
2021-05-30 layers: added v2/v3 layers for qaz 65%
    closes #4
    v2 has slightly altered holes on the top of the outline, since the SWD
    connector is not brought out.
    v3 is for using a pcb as the plate layer (not sure if it will work..)
    [QAZ_65-B_Cu.gbr, QAZ_65-B_Mask.gbr, QAZ_65-B_SilkS.gbr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]
2021-05-30 breakout: rgb conversion board
    Made a conversion board for the LED driver conversion board. The RGB
    LEDs chosen will not fit, and must be replaced in QAZ v1.1.
    [QAZ_65-B_Cu.gbr, QAZ_65-B_Mask.gbr, QAZ_65-B_SilkS.gbr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]
2021-05-30 cleanup: remove breakout boards
    No need to keep the breakout boards in the repo.
    [QAZ_IS31FL3746A_breakoutboard-B_Cu.gbr, QAZ_IS31FL3746A_breakoutboard-B_Mask.gbr, QAZ_IS31FL3746A_breakoutboard-B_SilkS.gbr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]
2021-05-31 plate-layer: added QAZ 65% PCB plate layer
    Since getting metal cut is expensive, and acrylic can't be used at a
    thickness of 1.6mm without breaking, a PCB can actually be used as the
    plate layer. For JLCPCB, it was less than $50 for 5 of these plate
    layers!
    [plate_layer_v3-B_Cu.gbr, plate_layer_v3-B_Mask.gbr, plate_layer_v3-B_Paste.gbr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]
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2021-06-03 bottom-plate: fixed hole alignment
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2021-06-17 qaz_media: added board for controlling media
    The QAZ Media board is meant to supplement the QAZ 65% keyboard, for
    doing things that can't be controlled by an HID Keyboard device.
    [QAZ_media-B_Cu.gbr, QAZ_media-B_Mask.gbr, QAZ_media-B_SilkS.gbr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]
2021-06-24 bom: fixed qaz media v1.0 bom
    Forgot the two 0.01uF caps.
    [QAZ_media_1v0_BOM.xlsx]
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2021-06-25 bsp: splitting of program based on bsp
    Well, this isn't a very good solution but it will work for now.
    I want to be able to easily switch in and out modules based on
    whether a particular board needs it. For example, the QAZ 65%
    needs lighting, the key matrix, and keyboard hid functionality. But the
    QAZ Media board doesn't need these.
    So how do I handle this? In a very non-scalable way. Each BSP has its
    own init which calls the appropriate inits, great. And the non-relevant
    content in the bsp header can be removed, great. But we are still
    compiling sources we don't need which causes compiler errors because we
    removed that content from the header. So now we also need to switch what
    we compil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
    [bsp_qaz_65.hpp, main.cpp]
2021-06-25 testboard: removed
    Removed all trace of the testboard, which is deprecated.
    [QAZ_externals.sch, QAZ_numpad_BOM.xlsx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]
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2021-06-27 consumer: copied kb hid driver
    Copy the kb hid driver for the consumer hid device. It doesn't send
    anything useful, but helps test functionality.
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2021-07-25 docs: splitting board-specific docs
    Split off info from README into several markdown files. Add guide for
    programming and USB software.
    [plate_layer_v2.dxf, plate_layer_v3.dxf]
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2021-08-30 qaz 65% v1.2: in-progress, updated pcb
    An issue seen with v1.1 (and v1.0 to a degree) was board warping. It's
    suspected that a copper imbalance causes this, since there is a full
    copper pour on the back of the board, and comparatively little copper on
    the front of the board.
    A ground pour was added to the top. This is desired over floating
    copper, but requires many ground via to stitch the pour to ground, and
    to prevent any antennae-like patches.
    Also slightly moved some of the in-board screw holes so that they don't
    brush up so close to key switches.
    [QAZ_65-B_Cu.gbr, QAZ_65-B_Mask.gbr, QAZ_65-B_SilkS.gbr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]
